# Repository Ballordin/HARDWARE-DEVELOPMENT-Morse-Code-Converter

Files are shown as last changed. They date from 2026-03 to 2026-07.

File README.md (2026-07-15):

#              Temperature to Morse Code Encoder

A professional embedded systems project developed for the Laboratory of Hardware Development (UTeSP - Sistemas Eletrónicos e Computadores). This device monitors ambient temperature using a PT100 sensor and encodes the data into Morse Code, delivered via audio (Buzzer) and visual (LED) signals.

## 🖼️ Hardware Preview

The PCB was designed and modeled in Altium Designer, featuring a compact layout and optimized signal paths for the PT100 conditioning circuit.

## 🛠️ Finished Physical Assembly

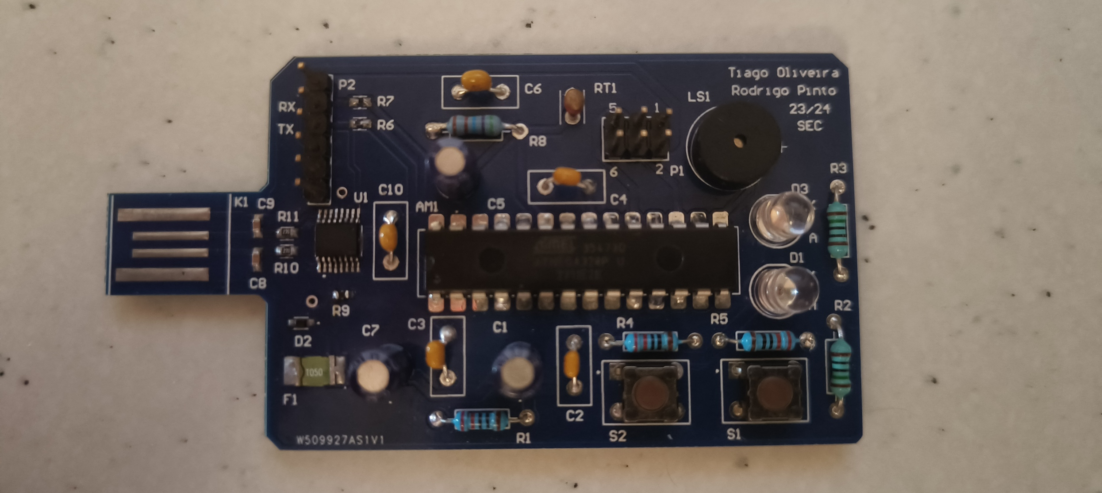
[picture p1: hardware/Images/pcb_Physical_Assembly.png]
Physical Manufactured PCB


## 💻 CAD Design

| 2D PCB Layout | 3D Model Render |
| :---: | :---: |
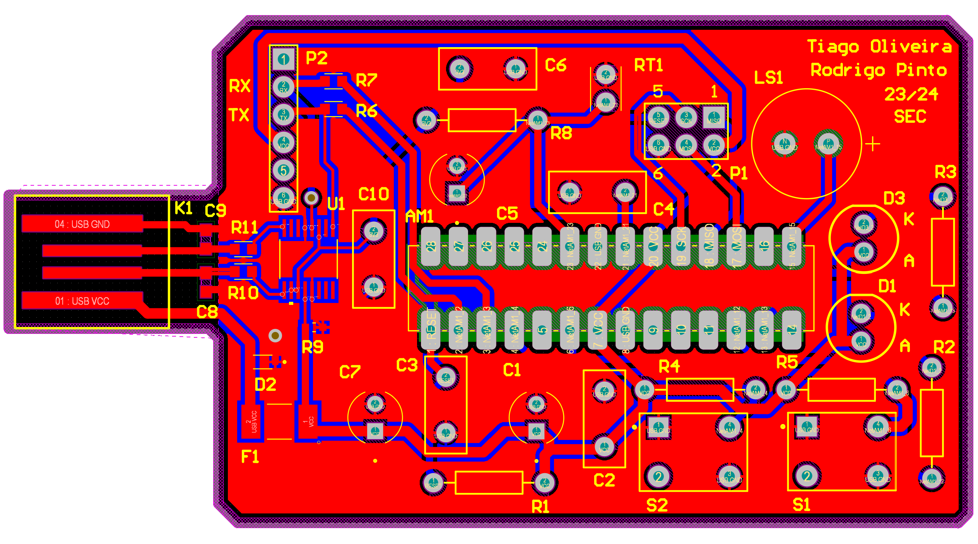
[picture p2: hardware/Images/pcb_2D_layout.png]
2D Layout
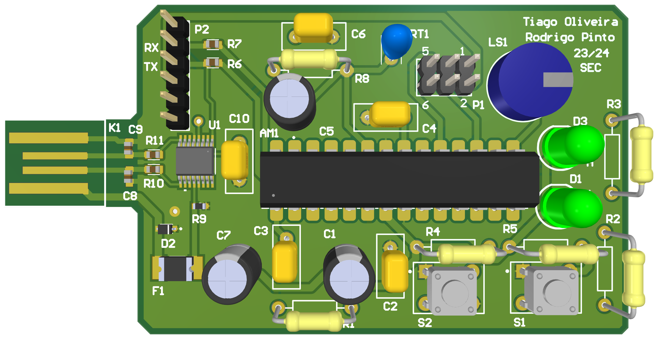
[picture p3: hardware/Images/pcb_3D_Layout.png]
3D Layout
|  |  |

## 🚀 Manufacturing Sponsorship & Quality Review

The physical hardware execution for this project was generously sponsored and fabricated by **PCBWay**. 

### 🌟 Experience & Quality of Service
Working with PCBWay was an absolute breeze from start to finish. A massive shoutout goes to **Liam from the Marketing Department** for reaching out, coordinating this partnership, and providing an immaculate, highly attentive service throughout the entire procurement cycle. 

The fabrication quality delivered by their engineering facility is exceptional:
* **Precision Trace Fabrication:** Flawless copper execution on both layers, accurately preserving the delicate analog signal tracks coming from the PT100 Wheatstone bridge conditioning circuit.
* **Solder Mask & Silk Screen Cleanliness:** The crisp, high-contrast white silk screening over the beautiful blue solder mask makes identifying component designators (like the PTC fuse and decoupling capacitors) effortless during manual assembly.
* **Mechanical Reliability:** Pristine via-plating and perfect drill alignments across all through-hole footprints, ensuring the DIP-28 socket and tactile switches seated perfectly flat against the substrate.

A huge thank you to Liam and the entire [PCBWay](https://www.pcbway.com) team for supporting student engineering projects and providing top-tier manufacturing turnaround!

## 📋 Project Overview

The system features two primary modes of operation, controlled via a TTL serial interface:
Mode 1 (Standard): Real-time temperature monitoring and encoding.
Mode 2 (Manual): Interruption of sensor reading to encode user-provided strings/characters received via UART.

Key Features & Commands
  - Microcontroller: ATmega328P (Running at 8MHz).
  - Baud Rate: 9600 bps (standard) / 115200 bps (high speed).
  - Interactive Commands:
      - '!' : Toggle output between LED and Buzzer.
      - '#' : Toggle between Temperature mode and Manual String mode.
      - '+' / '-' : Increment or decrement the Buzzer tone frequency (PWM).
  - Physical Interface: Two buttons to adjust the Morse transmission speed (BPS).

## 🛠 Hardware Design (Altium Designer)

The hardware focuses on signal integrity and cost-optimization.
  - Signal Conditioning: PT100 RTD integrated into a Wheatstone bridge for precise analog-to-digital conversion.
  - Buzzer: MP-ABI-050-RC (Low-power, 30mA), driven directly by the MCU.
  - Power & Protection: * Integrated USB-to-TTL conversion for power and data.
      - PTC Resettable fuse and decoupling capacitors (10µF and 100nF) for ADC stability and noise filtering.
      - Strategic use of SMD components for high-frequency performance and reliability.

## 💻 Firmware (Embedded C)

The software follows a modular architecture for better maintainability:
  - UART Driver: Custom asynchronous communication handler for serial commands.
  - GPIO & Morse Engine: Optimized dictionary for alphanumeric translation into timed Dot (200ms) and Dash (600ms) sequences.
  - PWM Control: Used for dynamic frequency adjustment of the audio output.
  - Interrupt Handling: Real-time UART RX processing to ensure no characters are lost during transmission.

## 📂 Repository Structure

  - /firmware: C source code, header files, and Atmel Studio project files.
  - /hardware: Altium Designer schematics, PCB layout, and manufacturing Gerbers.
  - /docs: Technical reports, market studies, and project planning.

## 👥 Author
  - Tiago Oliveira (25547)

Institution: IPCA - Escola Técnica Superior Profissional (2023/2024)

---------------------------------------------------------------------------------
## Developed as part of the Laboratory of Hardware Development Course.
---------------------------------------------------------------------------------

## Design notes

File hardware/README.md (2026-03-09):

🛠 Hardware Design

This folder contains all the hardware development files for the Morse Code Temperature Encoder, designed using Altium Designer.

📋 Technical Specifications

The PCB was designed to be a standalone shield/board based on the ATmega328P microcontroller, focused on precision sensing and signal conditioning.

1. Signal Conditioning (PT100 Sensor)
To accurately measure ambient temperature, a PT100 (RTD) sensor was used. Since the resistance variation of a PT100 is very small, the following was implemented:
  - Wheatstone Bridge: Used to convert resistance changes into a measurable voltage differential.
  - ADC Stability: A 100nF decoupling capacitor was placed close to the microcontroller's analog input to filter high-frequency noise and stabilize readings.
2. Power & Protection
  - Integrated USB-to-TTL: The board includes a dedicated section for USB communication, providing both power ($5$V) and data interface.
  - Circuit Protection: A PTC Resettable Fuse (MiniSMDC050F) was added to protect the USB port and the microcontroller from overcurrent.
  - Filtering: A combination of $10$µF electrolytic and $100$nF ceramic capacitors ensures a clean power rail for the MCU.
3. Components & I/O
  - Buzzer: MP-ABI-050-RC electro-mechanical buzzer.
      - Design Note: Selected specifically for its low current draw ($30$mA), allowing it to be driven directly by the ATmega328P I/O pin (max $40$mA) without needing an external transistor.
  - Visual Output: High-brightness Red LED for Morse signaling and a Yellow LED for system status/debugging.
  - User Interface: Two tactile switches for real-time BPS (Bits Per Second) adjustment.

📂 Folder Content

  - /Altium_Project: Native .PrjPcb, .SchDoc, and .PcbDoc files.
  - /Schematics: PDF version of the full circuit schematic.
  - /Gerber: Manufacturing files (RS-274X) for PCB production.
  - /BOM: Bill of Materials with specific Farnell/Mouser part numbers.
  
🖼 Preview

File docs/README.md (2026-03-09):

📄 Project Documentation

This folder contains the formal technical documentation, academic reports, and design analysis for the Morse Code Temperature Encoder project.

📂 Document Overview
1. Final Technical Report

The comprehensive final document covering the entire project lifecycle.

Contents: System architecture, hardware/software integration details, flowcharts, and final testing results.

Key Sections: Technical specifications of the ATmega328P, Morse algorithm implementation, and Wheatstone bridge calculations.

2. Analysis & Design Study
A detailed study of the components and theoretical foundations.

Contents: Market research for component selection (PT100, Buzzer, LEDs), cost analysis, and comparison between SMD vs. THT components for the USB interface.

3. Project Scope & Problem Statement
The initial planning phase of the project.

Contents: Definition of functional requirements (Mode 1: Temperature; Mode 2: Manual Serial Input), non-functional requirements (Baud rate, safety protocols), and project milestones.

4. Hardware Diagrams
Early-stage design concepts and block diagrams.

Contents: High-level system overview showing the interaction between the power protection circuit, the MCU, and the I/O peripherals.

🎓 Academic Context
Course: Laboratory of Hardware Development

Institution: IPCA - Escola Técnica Superior Profissional (Portugal)

Objective: To design a complete embedded system from scratch, including PCB manufacturing and firmware development in C.

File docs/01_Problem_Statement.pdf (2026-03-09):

Problem Statement

Neste documento serão discutidas as etapas para a realização de um projeto de medição de temperatura e conversão em código Morse através de saídas sonoras ou luminosas.

1º Passo – Medição de Temperatura

Para medir a temperatura, poderão ser utilizados sensores de temperatura, RTD, termopares ou termístores. Neste caso será usada uma PT100 numa ponte de wheatstone para fazer a medição de temperatura.

2º Passo – Conversão da Temperatura em Código MORSE

O 1º modo que será o modo standard onde a temperatura lida pelo sensor será codificada em código MORSE e enviada para a saída escolhida, luminosa ou sonora. Código MORSE é lido por “bips”, aos quais podem ser longos ou curtos, e a combinação destes “bips” longos ou curtos, dá origem a uma letra ou número. Sendo assim, neste 1º modo apenas a temperatura será lida em forma de código MORSE.

3º Passo – Conversão de Palavras/carateres emitidos pela porta-série em Código MORSE

O 2º modo consiste no envio de palavras pelo comando porta-série que também serão codificadas em código MORSE em saída luminosa ou sonora. A troca entre o 1º modo e o 2º modo será feita com um símbolo específico como “#” ou “*” enviada pela porta- série.

4º Passo – Saída Luminosa e Sonora

No nosso sistema existirão 2 saídas, saída luminosa ou saída sonora, onde para saída sonora usaremos um Buzzer e para saída luminosa usaremos um LED.

5º Passo – Reprodução do código MORSE por saída luminosa ou sonora

Para a escolha de saída, utilizamos o comando porta-série, onde escolhemos uma letra para representar a saída sonora “B” e outra letra para representar a saída luminosa “L”.

6º Passo – Configuração da frequência de som de operação

A duração da frequência do som de operação poderá ser configurada utilizando o baud_rate na programação do microcontrolador.

7º Passo – Botão para incrementar e decrementar bps

Haverá também um botão que incremente ou decremente a duração da frequência de operação.

a25547 – Tiago Oliveira

a25548 – Rodrigo Pinto

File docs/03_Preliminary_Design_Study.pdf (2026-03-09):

# Codificador de temperatura em Código Morse

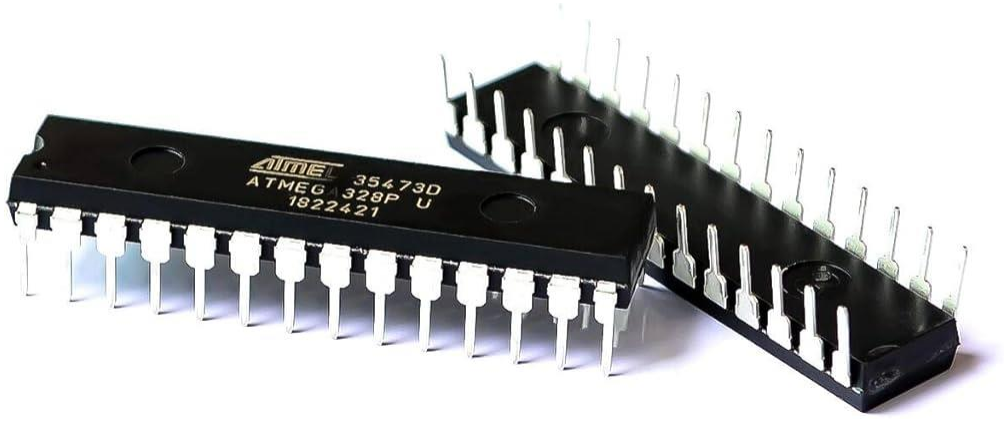
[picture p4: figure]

Tiago Oliveira - 25547
Rodrigo Pinto - 25548

# Problem Statement

O projeto que vamos criar terá dois modos de funcionamento.

## Modo 1: Medir a temperatura e reproduzir os dados em código Morse através de saídas sonoras ou luminosas (escolha feita enviando um comando

pela porta serie TTL).

## Modo 2: Interromper a leitura da temperatura enviando um carater pela porta série. Após essa interrupção será possível fazer a leitura de palavras/caracteres enviadas pela porta série. Leitura também reproduzida

em código Morse através de saídas sonoras ou luminosas.

## Outros requisitos deste projeto são: através de dois botões podemos incrementar ou decrementar os bps do sinal, receber comando para configurar a frequência de som. Usar obrigatoriamente o Baud rate a

115200bps.

# Project Scope

- TÍTULO DO PROJETO: Codificador de Temperatura em Código MORSE
- OBJETIVO DO PROJETO:
- Desenvolver um equipamento que monitora e codifica a temperatura ambiente em código Morse e exibe os resultados em um display LED ou em um Buzzer.
- DESCRIÇÃO DO PROJETO:
- Este projeto tem como objetivo desenvolver um dispositivo eletrônico que mede a temperatura ambiente por meio de um sensor de temperatura PT100 e codifica essa temperatura em código Morse. O dispositivo utilizará o microcontrolador ATmega328P para controlar duas saídas: luminosa (LED) e sonora (buzzer). A comunicação entre o dispositivo e um computador será feita por meio do comando porta série (UART) para configuração e monitorização da temperatura.
- ÂMBITO DO PROJETO:
- O desenvolvimento deste projeto será feito na unidade curricular de Laboratórios e Desenvolvimento de Hardware, proposto pelo prof.: Carlos Silva e Carlos Ferreira

# Block Diagram

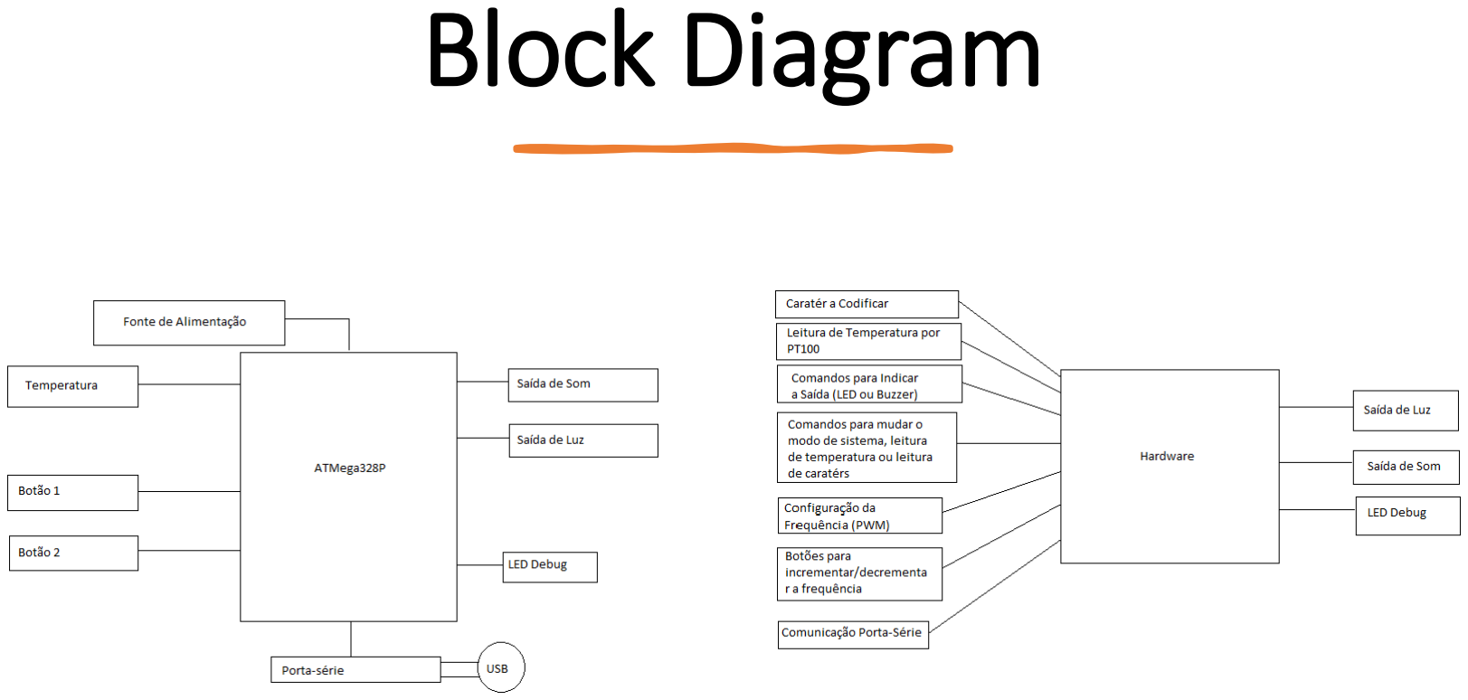
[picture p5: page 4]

# ATMega328P Design

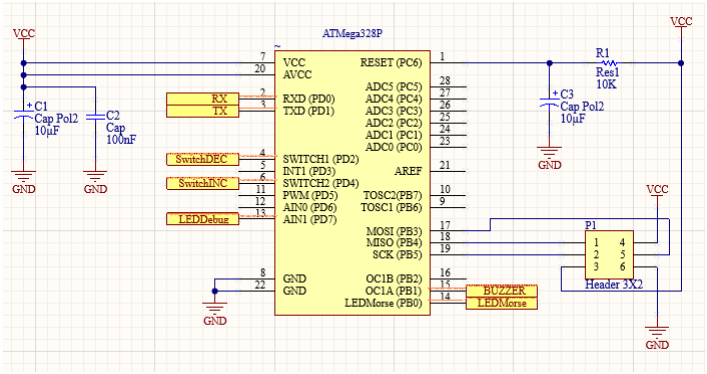
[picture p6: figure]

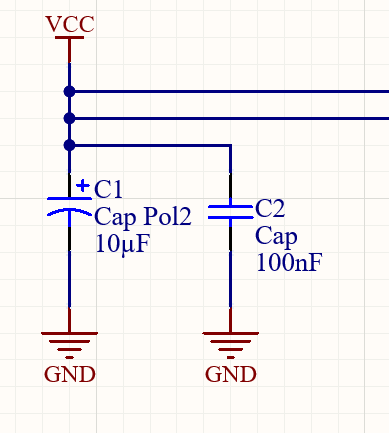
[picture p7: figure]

# ATMega328P Power Circuit

- O ATmega328P precisa de alimentação, sendo assim são utilizado dois condensadores (CAP) ligado ao ground (GND) e à tensão de alimentação (VCC).Este circuito de alimentação tem várias vantagens:
- Filtragem de Ruído: Um condensador pode ser usado para filtrar ruídos e picos de tensão de alta frequência do circuito de alimentação. Um segundo condensador pode ser dimensionado para filtrar ruídos de frequência mais baixa. Isso ajuda a manter uma alimentação mais limpa e estável para os dispositivos que utilizam a energia elétrica.
- Redundância e Confiabilidade
- Tempo de Resposta Rápido

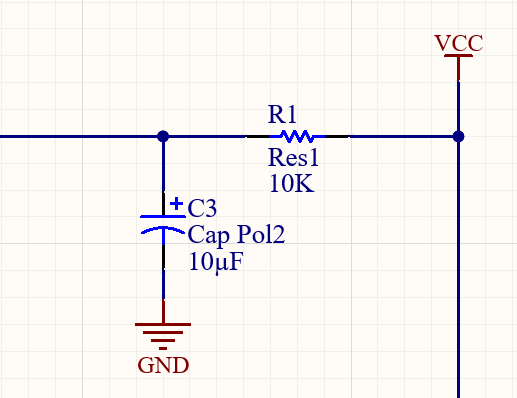
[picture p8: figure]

# ATMega328P Reset Circuit

Uma resistência de pull-up é frequentemente usada em circuitos de reset para garantir que o estado do sinal de reset seja bem definido quando não está sendo ativamente acionado.
Garantia de Estado Lógico: A resistência de pull-up assegura que o sinal de reset permaneça em um estado lógico específico (geralmente "1" ou "alto") quando nenhum outro dispositivo o puxa para um estado lógico "0" ou "baixo". Isso evita estados indefinidos que podem ocorrer quando o sinal de reset fica flutuante.
Temporização de Reset Controlada: O condensador, em conjunto com a resistência (em um circuito RC), pode ser usado para criar um atraso controlado na ativação do reset. O tempo necessário para carregar ou descarregar o condensador determina o atraso na ativação. Isso é útil para garantir que o reset não ocorra imediatamente quando a energia é aplicada, permitindo que o sistema se estabilize primeiro.

# Input Block (Botões)

- Nos diferentes tipos de esquema para montagem de switch, optamos por este tipo de montagem.
- Como a resistência é ligada ao VCC, existirá sempre pull-up interno ou externo mesmo que o pino não esteja bem configurado.
- Mesmo sabendo que o microcontrolador internamente tem uma Resistencia de pull-up mesmo assim decidimos colocar uma Resistencia de pull-up externa

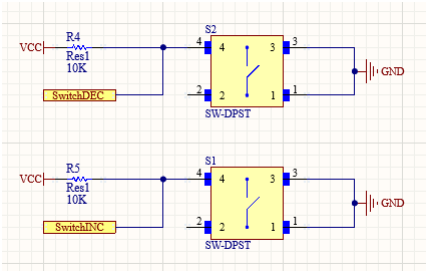
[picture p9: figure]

Possui certas vantagens como:
- Estabilidade: Um resistor de pull-up garante que a entrada permaneça em nível alto (geralmente nível lógico 1) quando o interruptor estiver aberto. Isso evita flutuações indesejadas na entrada.
- Evita curto-circuitos
- Debouncing

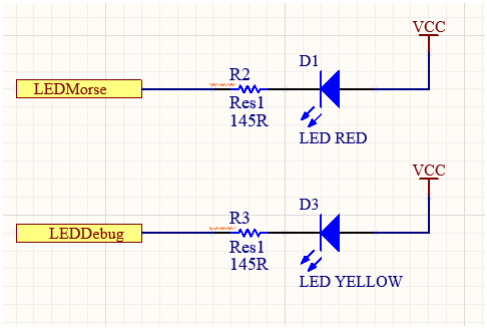
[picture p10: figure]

# Output Block (LED’s)

Calculo de resistências e correntes:

(LED RED)
VFtyp = 2.1V
Ifmax = 20mA
V_LedR = 5 – 2.1 = 2.9V
R_ledR = 2.9/20m = 145 Ω
(Não podemos usar uma resistência inferior a 145 Ω quando alimentada a 5V, pois a probabilidade de danificar o led e as portas do microcontrolador é grande).

(LED YELLOW)
VFtyp = 2.1 V
Ifmax = 20mA
V_ledY = 5 – 2.1 = 2.9V
R_ledY = 2.9/20m = 145 Ω
(Não podemos usar uma resistência inferior a 145 Ω quando alimentada a 5V, pois a probabilidade de danificar o led e as portas do microcontrolador é grande).

# Output Block

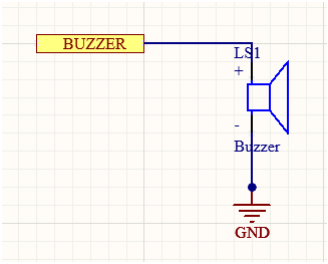
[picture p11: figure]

# (Buzzer)

- Vamos conectar o Buzzer a um PWM.
- Os buzzers tradicionalmente emitem um som com intensidade sonora constante quando alimentados com uma tensão constante. Ao usar um sinal PWM, podemos variar a tensão eficaz aplicada ao buzzer, o que resulta em uma variação na intensidade sonora do som. Isso é útil quando você deseja ajustar o volume do som em um dispositivo ou sistema.

# Output/Input (Conetor Porta-série)

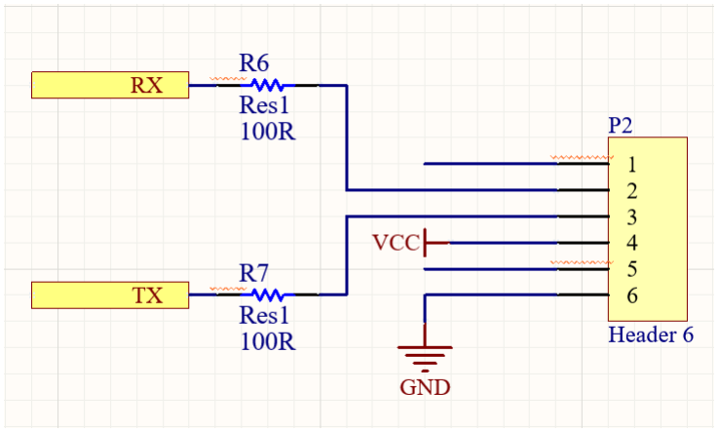
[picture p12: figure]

- Como no nosso projeto será necessária a comunicação porta-série para comunicar entre o utilizador e o microcontrolador, utilizamos o Adaptador série USB para TTL para fazer essas comunicações e assim não necessitamos de adicionar um bloco de conversão UART para fazer essas comunicações.
- As linhas TX e RX do programador são utilizadas para realizar comunicação série assíncrona. Quando o programador recebe um byte do computador via USB, esse byte será transmitido na Linha TX. Quando o programador recebe um byte na linha de entrada RX, esse byte será enviado de volta para o computador através de USB.
- O programador suporta todas as taxas de transmissão inteiras de 300 a 115200bits por segundo, que no nosso caso será feita a 115200 bits, um dos requisitos do nosso projeto.

# Comparação de

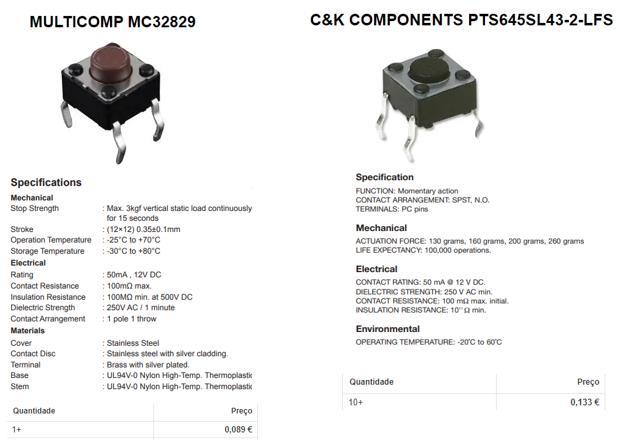
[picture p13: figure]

# Botões

### Neste caso optei pelo tactile switch mais barato, pois ambos os componentes tem características de funcionamento idênticas e cumpre com todos os requisitos necessários para

o nosso projeto.

# Comparação de LED’s (Red)

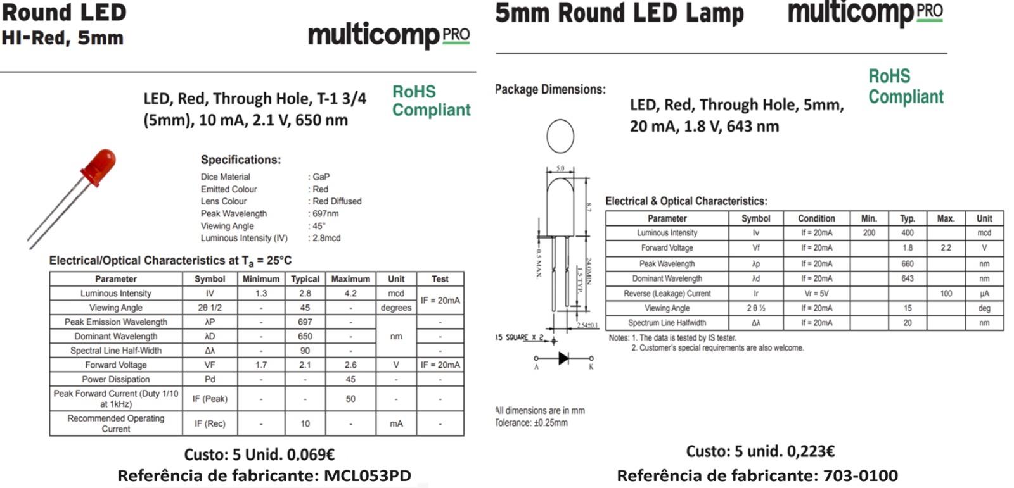
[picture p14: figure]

# Comparação de LED’s (Yellow)

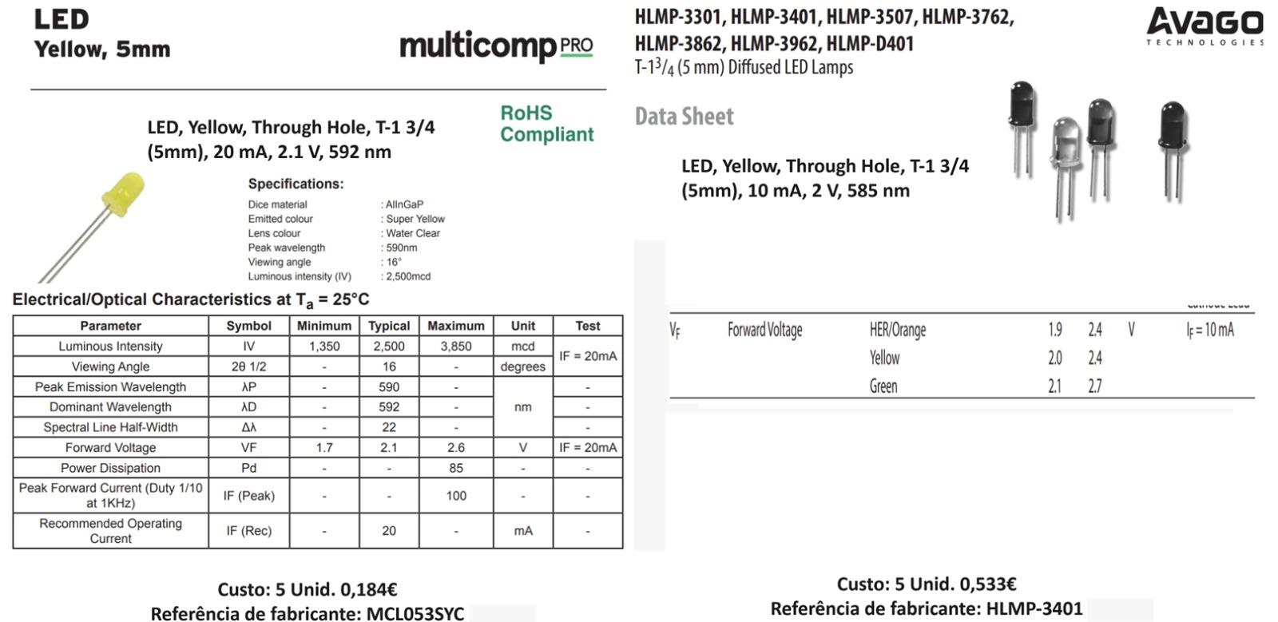
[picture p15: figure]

## - Optei por escolher o MULTICOMP PRO MCL053PD LED, Red, Through Hole, T-1 3/4 (5mm), 10 mA, 2.1 V, 650 nm porque é o componente mais barato entre os dois escolhidos e tendo os dois características idênticas, são ideais para utilizar no nosso

projeto com os requisitos fornecidos.

## - MULTICOMP PRO MCL053SYC LED, Yellow, Through Hole, T-1 3/4 (5mm), 20 mA, 2.1 V, 592 nm porque é o componente mais barato entre os dois escolhidos e tendo os dois características idênticas, são ideais para utilizar no nosso

projeto com os requisitos fornecidos.

# Comparação

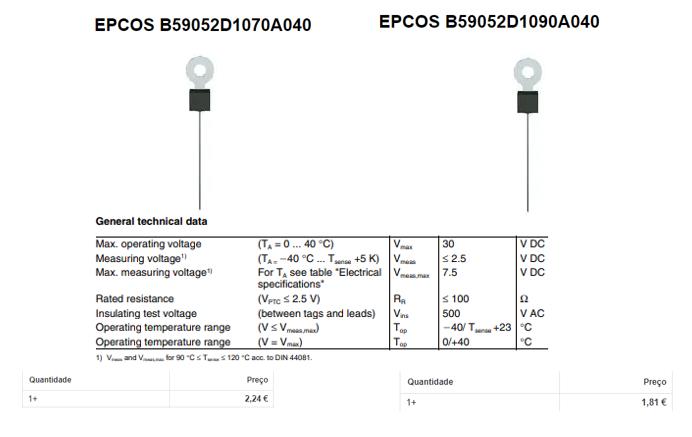
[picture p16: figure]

# Sensores de Temperatura

### - Neste caso optei pelo sensor de temperature mais barato, pois ambos os sensores tem características de funcionamento iguais e cumprem com os requisitos necessários

para o nosso projeto.

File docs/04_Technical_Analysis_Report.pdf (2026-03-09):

# Codificador de temperatura em Código Morse

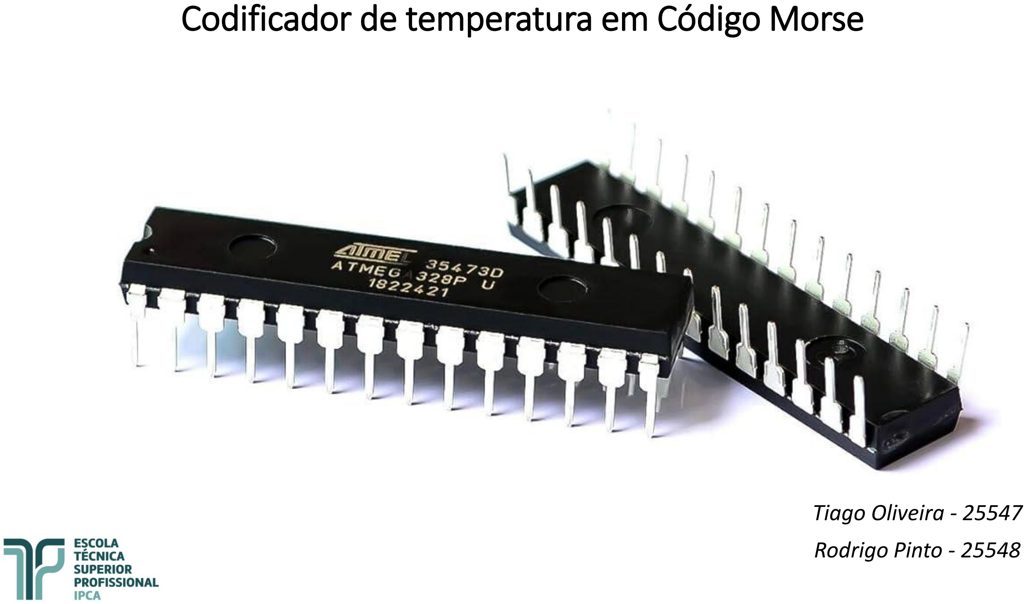
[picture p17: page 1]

### Tiago Oliveira - 25547 Rodrigo Pinto - 25548

# Problem Statement

O projeto que vamos criar terá dois modos de funcionamento.
Modo 1: Medir a temperatura e reproduzir os dados em código Morse através de saídas sonoras ou luminosas (escolha feita enviando um comando pela porta serie TTL).
Modo 2: Interromper a leitura da temperatura enviando um carater pela porta série. Após essa interrupção será possível fazer a leitura de palavras/caracteres enviadas pela porta série. Leitura também reproduzida em código Morse através de saídas sonoras ou luminosas.
Outros requisitos deste projeto são: através de dois botões podemos incrementar ou decrementar os bps do sinal, receber comando para configurar a frequência de som. Usar obrigatoriamente o Baud rate a 115200bps.

# Project Scope

- TÍTULO DO PROJETO: Codificador de Temperatura em Código MORSE
- OBJETIVO DO PROJETO:
- Desenvolver um equipamento que monitora e codifica a temperatura ambiente em código Morse e exibe os resultados em um display LED ou em um Buzzer.
- DESCRIÇÃO DO PROJETO:
- Este projeto tem como objetivo desenvolver um dispositivo eletrônico que mede a temperatura ambiente por meio de um sensor de temperatura PT100 e codifica essa temperatura em código Morse. O dispositivo utilizará o microcontrolador ATmega328P para controlar duas saídas: luminosa (LED) e sonora (buzzer). A comunicação entre o dispositivo e um computador será feita por meio do comando porta série (UART) para configuração e monitorização da temperatura.
- ÂMBITO DO PROJETO:
- O desenvolvimento deste projeto será feito na unidade curricular de Laboratórios e Desenvolvimento de Hardware, proposto pelo prof.: Carlos Silva e Carlos Ferreira

# Block Diagram

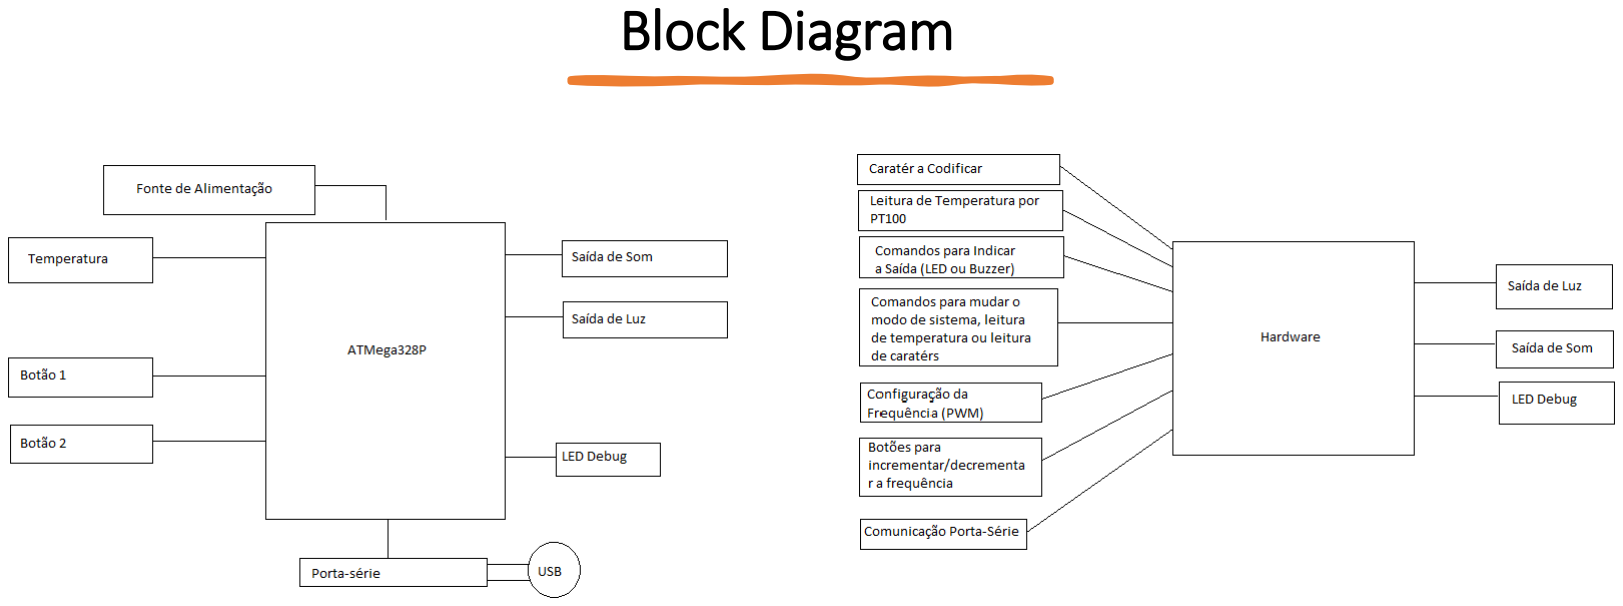
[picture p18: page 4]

# ATMega328P Design

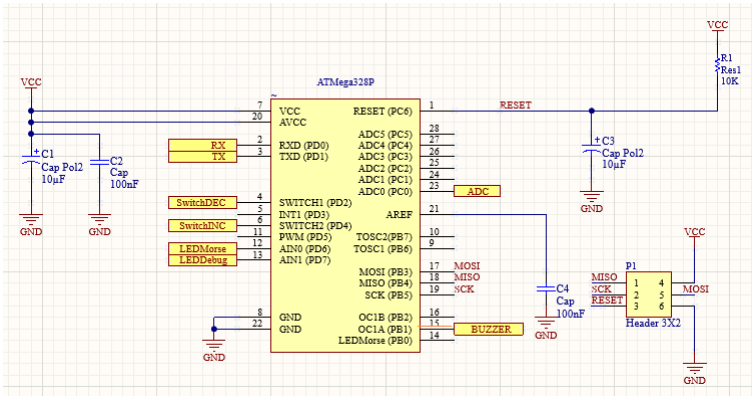
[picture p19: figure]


# ATMega328P Power Circuit

O ATmega328P precisa de alimentação, sendo assim são utilizados dois condensadores (CAP) ligado ao ground (GND) e à tensão de alimentação (VCC) . Este circuito de alimentação tem várias vantagens:

- Filtragem de Ruído: Um condensador pode ser usado para filtrar ruídos e picos de tensão de alta frequência. Um segundo condensador pode ser dimensionado para filtrar ruídos de frequência mais baixa. Isso ajuda a manter uma alimentação mais limpa e estável.
- Redundância e Confiabilidade
- Tempo de Resposta Rápido

# ATMega328P Reset Circuit

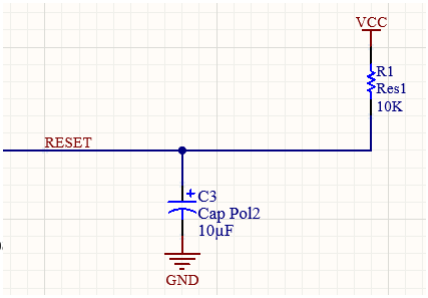
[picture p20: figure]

Uma resistência de pull-up é frequentemente usada em circuitos de reset para garantir que o estado do sinal de reset seja bem definido quando não é ativamente acionado.
Garantia de Estado Lógico: A resistência de pull-up assegura que o sinal de reset permaneça em um estado lógico específico (geralmente"1“)quando nenhum outro dispositivo o puxa para um estado lógico "0". Assim evita estados indefinidos que podem ocorrer quando o sinal de reset fica flutuante. Temporização de Reset Controlada: O condensador, em conjunto com a resistência (em um circuito RC), pode ser usado para criar um atraso controlado na ativação do reset. O tempo necessário para carregar ou descarregar o condensador determina o atraso na ativação. É útil para garantir que o reset não ocorra imediatamente quando a energia é aplicada, fazendo com que o sistema se estabilize primeiro.

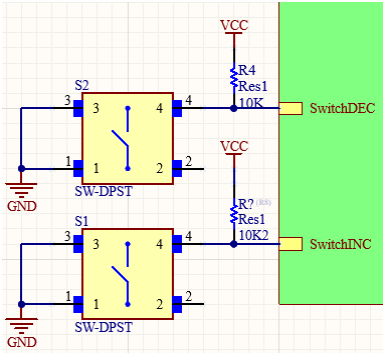
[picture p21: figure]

# Input Block (Botões)

- Nos diferentes tipos de esquema para montagem de switch, optamos por este tipo de montagem.
- Como a resistência é ligada ao VCC, existirá sempre pull-up interno ou externo mesmo que o pino não esteja bem configurado.
- Sabendo que o microcontrolador internamente tem uma Resistencia de pull-up mesmo assim decidimos
colocar uma Resistencia de pull-up externa.
Possui certas vantagens como:
- Estabilidade: Um resistor de pull-up garante que a entrada permaneça em nível alto (nível lógico 1) quando o interruptor estiver aberto. Isso evita flutuações indesejadas na entrada.
- Evita curto-circuitos
- Debouncing

# Input Block (Sensor de Temperatura)

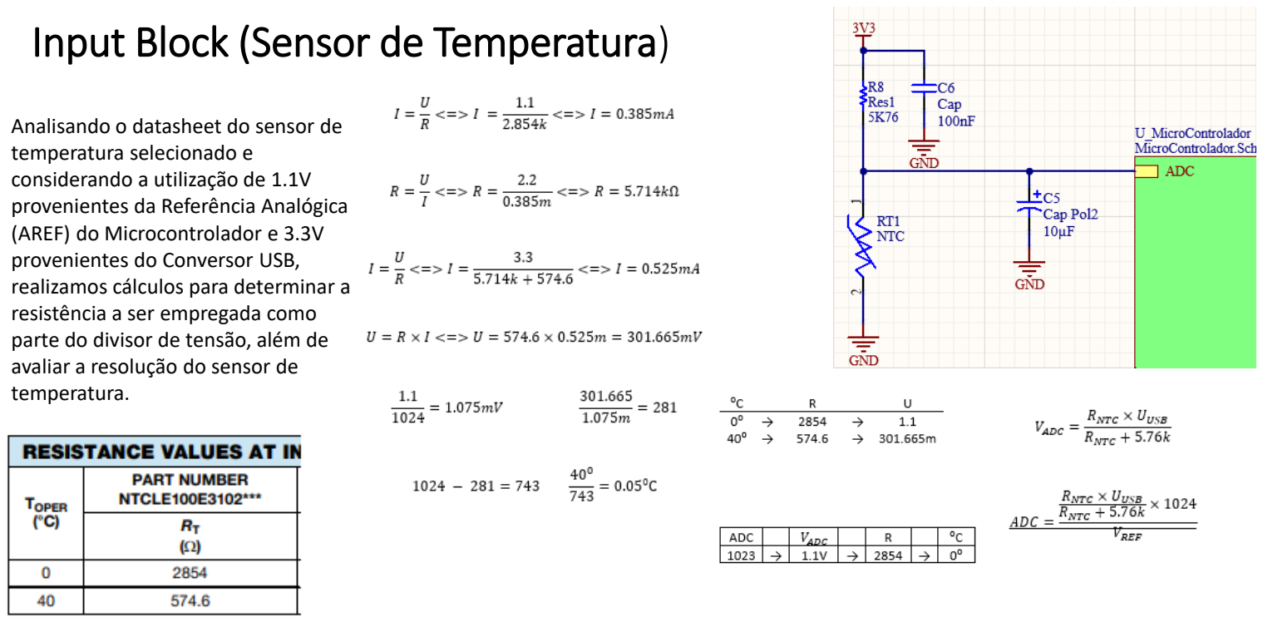
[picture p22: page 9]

Analisando o datasheet do sensor de temperatura selecionado e
considerando a utilização de 1.1V provenientes da Referência Analógica (AREF) do Microcontrolador e 3.3V provenientes do Conversor USB, realizamos cálculos para determinar a resistência a ser empregada como parte do divisor de tensão, além de avaliar a resolução do sensor de temperatura.

# AREF

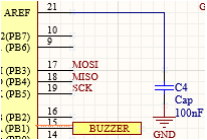
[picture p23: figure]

Usamos o AREF como referência analógica para o ADC.

Conectamos o AREF a um capacitor de 100nF porque ajuda a filtrar ruídos, estabilizar a referência de tensão, compensar correntes de pico e reduzir efeitos de indutância.

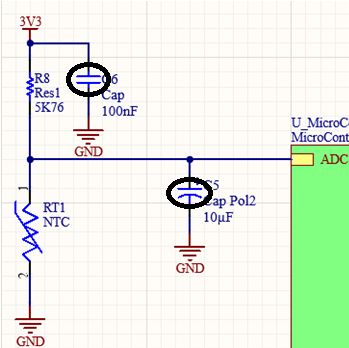
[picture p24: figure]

# Input Block (Sensor de Temperatura)

Estes condensadores de acoplamento possui vantagens para a alimentação do nosso ADC:
- Estabilidade de tensão
O Condensador de 10µF fornece corrente contínua mais estável e suaviza as variações de tensão de alimentação.
- Filtragem de Ruído de Alta Frequência
O Condensador de 100nF é eficaz a filtrar ruídos de alta frequência,ou seja, faz com que o ADC receba uma alimentação o mais limpa possível.
- Resposta Rápida a Variações de Carga
A combinação de condensadores de diferentes valores oferece uma resposta mais eficiente a variações rápidas de carga, garantindo uma alimentação estável.
- Redução de Ripple
O condensador de 10 µF é mais eficaz em lidar com variações de baixa frequência, enquanto o condensador de 100 nF atua em frequências mais altas. Juntos, ajudam a reduzir o ripple na linha de alimentação, proporcionando uma tensão mais constante para o ADC.

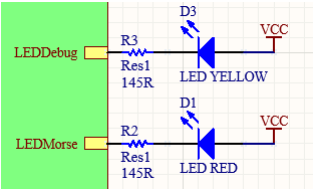
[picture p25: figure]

# Output Block (LED’s)

Calculo de resistências e correntes:

(LED RED)
VFtyp = 2.1V
Ifmax = 20mA
V_LedR = 5 – 2.1 = 2.9V
R_ledR = 2.9/20m = 145 Ω
(Não podemos usar uma resistência inferior a 145 Ω quando alimentada a 5V, pois a probabilidade de danificar o led e as portas do microcontrolador é grande).

(LED YELLOW)
VFtyp = 2.1 V
Ifmax = 20mA
V_ledY = 5 – 2.1 = 2.9V
R_ledY = 2.9/20m = 145 Ω
(Não podemos usar uma resistência inferior a 145 Ω quando alimentada a 5V, pois a probabilidade de danificar o led e as portas do microcontrolador é grande).

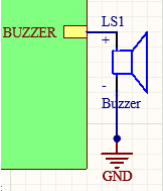
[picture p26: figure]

# Output Block (Buzzer)

Vamos conectar o Buzzer a um PWM.
Ao usar um sinal PWM, podemos variar a tensão eficaz aplicada ao buzzer, o que resulta em uma variação na intensidade sonora do som.
Apenas conectamos um pino à alimentação e o outro pino conectado ao GND. A razão para conectar apenas um terminal do buzzer ao GND é que o circuito interno do buzzer já possui uma conexão entre o terminal positivo e o negativo. Portanto, ao conectar o terminal positivo a uma fonte de alimentação e o terminal negativo (ou GND) ao ponto de referência comum do circuito, o circuito interno do buzzer fica completo.

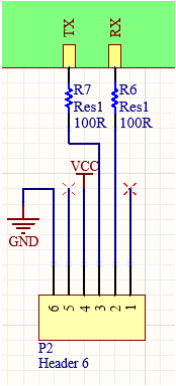
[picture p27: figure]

# Conetor Porta-série

- Como no nosso projeto será necessária a comunicação porta-série para comunicar entre o utilizador e o microcontrolador, utilizamos o Adaptador série USB para TTL para fazer essas comunicações e assim não necessitamos de adicionar um bloco de conversão UART para fazer essas comunicações.
- As linhas TX e RX do programador são utilizadas para realizar comunicação série assíncrona. Quando o programador recebe um byte do computador via USB, esse byte será transmitido na Linha TX. Quando o programador recebe um byte na linha de entrada RX, esse byte será enviado de volta para o computador através de USB.
- O programador suporta todas as taxas de transmissão inteiras de 300 a 115200bits por segundo, que no nosso caso será feita a 115200 bits, um dos requisitos do nosso projeto.

# Conetor Programação

O conector usado para fazer a programação e a comunicação para o microcontrolador é o Pololu USB AVR Programmer v2.1 que usa os pinos MOSI (Master Out Slave In), MISO (Master In Slave Out), SCK (Serial Clock), RESET, VCC (Alimentação) e GND (Terra).


Aqui estão as funções comuns desses pinos:
MOSI (Master Out Slave In): É a linha de dados. No contexto de programação de microcontroladores, este é o canal usado para enviar dados do programador para o microcontrolador.
MISO (Master In Slave Out): É a linha de dados. Utilizado para enviar dados do microcontrolador para o programador.
SCK (Serial Clock): É o sinal de clock . Sincroniza a transferência de dados nos pinos MOSI e MISO.
RESET: Este pino é usado para reiniciar o microcontrolador.
VCC (Alimentação): Este pino fornece a tensão de alimentação ao microcontrolador.
GND (Terra): Fornece um ponto de referência comum para a operação do circuito.

# Circuito de Proteção à Alimentação

Fusível Rearmável:


O fusível é colocado na linha de alimentação para interromper o circuito em caso de correntes anormais, como curtos-circuitos ou sobrecargas.
Díodo TVS:
O díodo é colocado na linha de alimentação para garantir que a corrente flua em uma única direção.
Varistor TVS :
São utilizados para limitar picos de tensão, como os causados por descargas atmosféricas. O varistor conduz corrente quando a tensão ultrapassa um certo limiar, desviando a energia prejudicial e protegendo os dispositivos conectados.
Condensador (filtro de entrada):
O condensador ajuda a filtrar ruídos e picos de tensão que podem ser prejudiciais aos dispositivos conectados.

Como o nosso circuito será alimentado através da porta USB, adotamos componentes essenciais para assegurar a segurança da nossa placa.


# USB Converter

Resistores de 27 ohms : Estas resistências geralmente são utilizadas como resistências de carga. As resistências de carga ajudam a ajustar a impedância do circuito e a garantir que o sinal seja transmitido corretamente.
Condensadores de 47pF : Os condensadores de 47pF são geralmente usados para filtrar ruídos de alta frequência e para ajudar a estabilizar o sinal.
Condensador de 10nF : Este condensador pode ser utilizado para acoplar o sinal, bloqueando qualquer componente DC que possa estar presente, ajuda a garantir que apenas a componente de AC do sinal seja transmitida através do circuito.
Condensador de 100nF : Similar ao capacitor de 10nF, o capacitor de 100nF também pode ser utilizado para acoplamento AC e para ajudar a estabilizar a alimentação do circuito.

# IMPORTÂNCIA DO USO DE SMD

Aqui estão algumas razões pelas quais os componentes SMD são frequentemente preferidos em circuitos de USB Converter:

Desempenho de Alta Frequência:
Componentes SMD têm características elétricas e mecânicas que os tornam ideais para operar em frequências mais altas. Isso é relevante em circuitos de USB Converter, que podem envolver sinais de alta frequência para garantir a transferência eficiente de dados.
Melhor Desempenho Elétrico:
Os componentes SMD geralmente têm características elétricas superiores, como menor indutância e resistência, quando comparados aos componentes tradicionais. Isso é benéfico para garantir um desempenho elétrico mais estável e eficiente.
Aprimoramento da Confiabilidade:
A montagem superficial oferece uma conexão mais direta entre os componentes e a placa de circuito, reduzindo a probabilidade de problemas de soldagem, especialmente em condições de vibração ou variações de temperatura.

# Comparação de Botões

Neste caso optei pelo tactile switch mais barato, pois ambos os componentes tem características de funcionamento idênticas e cumpre com todos os requisitos necessários para o nosso projeto.


https://pt.farnell.com/multicomp/mc32829/tactile-switch-spst-no-0-05a-12v/dp/2543090 (https://pt.farnell.com/multicomp/mc32829/tactile-switch-spst-no-0-05a-12v/dp/2543090) https://pt.farnell.com/c-kcomponents/pts645sl43-2-lfs/tactile-switch-spst-0-05a-12vdc/dp/2435161 (https://pt.farnell.com/c-k-components/pts645sl43-2-lfs/tactile-switch-spst-0-05a-12vdc/dp/2435161)

# Sensor de Temperatura (NTC)

PTC (Positive Temperature Coefficient):
A resistência elétrica de um PTC aumenta com o aumento da temperatura. Ou seja, à medida que a temperatura sobe, a resistência elétrica da PTC também aumenta e a corrente elétrica diminui.
Tendem a ser mais estáveis termicamente em comparação com NTCs.

NTC (Negative Temperature Coefficient):
Ao contrário do PTC, a resistência elétrica de um NTC diminui com o aumento da temperatura. À medida que a temperatura aumenta, a resistência elétrica do NTC diminui e a corrente elétrica aumenta.
Pode ser menos estável termicamente, especialmente em altas temperaturas.

Este foi o sensor de temperatura escolhido por nós, além de ter amplitude de leitura de temperatura requisitada para o nosso sistema,
é o sensor de temperatura mais barato encontrado na FARNELL.


https://pt.farnell.com/vishay/ntcle100e3102jb0a/ntc-thermistor-1kradial-leaded/dp/3020808 (https://pt.farnell.com/vishay/ntcle100e3102jb0a/ntc-thermistor-1k-radial-leaded/dp/3020808)

# Comparação de LED’s (Red)


https://pt.farnell.com/multicomp-pro/mcl053pd/led-5mm-36-hi-red/dp/1581136 (https://pt.farnell.com/multicomp-pro/mcl053pd/led-5mm-36-hi-red/dp/1581136)

https://pt.farnell.com/multicomp/703-0100/led-5mm-red-400mcd-643nm/dp/2112111 (https://pt.farnell.com/multicomp/703-0100/led-5mm-red-400mcd-643nm/dp/2112111)

# Comparação de LED’s (Yellow)


https://pt.farnell.com/multicomp/mcl053syc/led-5mm-16-yellow/dp/1581180 (https://pt.farnell.com/multicomp/mcl053syc/led-5mm-16-yellow/dp/1581180)

https://pt.farnell.com/broadcomlimited/hlmp-3401/led-5mmyellow-5-7mcd-585nm/dp/1003213 (https://pt.farnell.com/broadcom-limited/hlmp-3401/led-5mm-yellow-5-7mcd-585nm/dp/1003213)

- Optei por escolher o MULTICOMP PRO MCL053PD
LED, Red, Through Hole, T-1 3/4 (5mm), 10 mA, 2.1 V, 650 nm
porque é o componente mais barato entre os dois escolhidos e tendo os dois características idênticas, são ideais para utilizar no nosso projeto com os requisitos fornecidos.
- MULTICOMP PRO MCL053SYC
LED, Yellow, Through Hole, T-1 3/4 (5mm), 20 mA, 2.1 V, 592 nm
porque é o componente mais barato entre os dois escolhidos e tendo os dois características idênticas, são ideais para utilizar no nosso projeto com os requisitos fornecidos.

# COMPARAÇÃO DE BUZZER’S


Apesar de ambos os buzzers terem as especificações necessárias ao nosso projeto e terem ambos o mesmo preço de compra, escolhemos o buzzer MP-ABI-050-RC porque sendo a corrente máxima do buzzer 30mA e a corrente máxima da porta do microcontrolador ser 40mA, o buzzer pode ser diretamente conectado à porta.
No caso do outro buzzer, em que a corrente máxima é 50mA, seria necessário o uso de um transitor para controlar a corrente que passaria do buzzer para o pino do microcontrolador.

https://pt.farnell.com/prosignal/abi-050-rc/buzzer-electromechanical-5vdc/dp/2534976 (https://pt.farnell.com/pro-signal/abi-050-rc/buzzer-electro-mechanical-5vdc/dp/2534976)

https://pt.farnell.com/prosignal/abt-414-rc/transducerelectro-mech-audio/dp/2098836 (https://pt.farnell.com/pro-signal/abt-414-rc/transducer-electro-mech-audio/dp/2098836)

# Circuito de Proteção à Alimentação (COMPONENTES)


https://pt.farnell.com/littelfuse/minismdc050f-2/ptc-resettable-fuse-24vdc-1812/dp/1175839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 (https://pt.farnell.com/littelfuse/minismdc050f-2/ptc-resettable-fuse-24vdc-1812/dp/1175839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) https://pt.mouser.com/ProductDetail/Littelfuse/AQ1205-01FTG?qs=tlsG%2FOw5FFgT8
17I6cPGrg%3D%3D (https://pt.mouser.com/ProductDetail/Littelfuse/AQ1205-01FTG?qs=tlsG%2FOw5FFgT817I6cPGrg%3D%3D)

https://pt.farnell.com/yageo/241kd07-tr/varistor-mov-395vdisc-7mm/dp/3052479 (https://pt.farnell.com/yageo/241kd07-tr/varistor-mov-395v-disc-7mm/dp/3052479)

# USB Converter


Este é o componente que será usado para fazer a conversão de sinais de comunicação USB para sinais de comunicação UART.

https://pt.farnell.com/ftdi/ft230xs-xr/i-f-usb2-0-fs-to-basicuart-16ssop/dp/2081321?st=ftdi%20ft230xs-r (https://pt.farnell.com/ftdi/ft230xs-xr/i-f-usb2-0-fs-to-basic-uart-16ssop/dp/2081321?st=ftdi%20ft230xs-r)

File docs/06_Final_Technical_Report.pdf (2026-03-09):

# Codificador de temperatura em Código Morse


### Tiago Oliveira - 25547 Rodrigo Pinto - 25548

# Problem Statement

O projeto que vamos criar terá dois modos de funcionamento.
Modo 1: Medir a temperatura e reproduzir os dados em código Morse através de saídas sonoras ou luminosas (escolha feita enviando um comando pela porta serie TTL).
Modo 2: Interromper a leitura da temperatura enviando um carater pela porta série. Após essa interrupção será possível fazer a leitura de palavras/caracteres enviadas pela porta série. Leitura também reproduzida em código Morse através de saídas sonoras ou luminosas.
Outros requisitos deste projeto são: através de dois botões podemos incrementar ou decrementar os bps do sinal, receber comando para configurar a frequência de som. Usar obrigatoriamente o Baud rate a 115200bps.

# Project Scope

- TÍTULO DO PROJETO: Codificador de Temperatura em Código MORSE
- OBJETIVO DO PROJETO:
- Desenvolver um equipamento que monitora e codifica a temperatura ambiente em código Morse e exibe os resultados em um display LED ou em um Buzzer.
- DESCRIÇÃO DO PROJETO:
- Este projeto tem como objetivo desenvolver um dispositivo eletrônico que mede a temperatura ambiente por meio de um sensor de temperatura PT100 e codifica essa temperatura em código Morse. O dispositivo utilizará o microcontrolador ATmega328P para controlar duas saídas: luminosa (LED) e sonora (buzzer). A comunicação entre o dispositivo e um computador será feita por meio do comando porta série (UART) para configuração e monitorização da temperatura.
- ÂMBITO DO PROJETO:
- O desenvolvimento deste projeto será feito na unidade curricular de Laboratórios e Desenvolvimento de Hardware, proposto pelo prof.: Carlos Silva e Carlos Ferreira

# Comparação de Botões

Neste caso optei pelo tactile switch mais barato, pois ambos os componentes tem características de funcionamento idênticas e cumpre com todos os requisitos necessários para o nosso projeto.


https://pt.farnell.com/multicomp/mc32829/tactile-switch-spst-no-0-05a-12v/dp/2543090 (https://pt.farnell.com/multicomp/mc32829/tactile-switch-spst-no-0-05a-12v/dp/2543090) https://pt.farnell.com/c-kcomponents/pts645sl43-2-lfs/tactile-switch-spst-0-05a-12vdc/dp/2435161 (https://pt.farnell.com/c-k-components/pts645sl43-2-lfs/tactile-switch-spst-0-05a-12vdc/dp/2435161)

# Sensor de Temperatura (NTC)

PTC (Positive Temperature Coefficient):
A resistência elétrica de um PTC aumenta com o aumento da temperatura. Ou seja, à medida que a temperatura sobe, a resistência elétrica da PTC também aumenta e a corrente elétrica diminui.
Tendem a ser mais estáveis termicamente em comparação com NTCs.

NTC (Negative Temperature Coefficient):
Ao contrário do PTC, a resistência elétrica de um NTC diminui com o aumento da temperatura. À medida que a temperatura aumenta, a resistência elétrica do NTC diminui e a corrente elétrica aumenta.
Pode ser menos estável termicamente, especialmente em altas temperaturas.

Este foi o sensor de temperatura escolhido por nós, além de ter amplitude de leitura de temperatura requisitada para o nosso sistema,
é o sensor de temperatura mais barato encontrado na FARNELL.


https://pt.farnell.com/vishay/ntcle100e3102jb0a/ntc-thermistor-1kradial-leaded/dp/3020808 (https://pt.farnell.com/vishay/ntcle100e3102jb0a/ntc-thermistor-1k-radial-leaded/dp/3020808)

# Comparação de LED’s (Red)


https://pt.farnell.com/multicomp-pro/mcl053pd/led-5mm-36-hi-red/dp/1581136 (https://pt.farnell.com/multicomp-pro/mcl053pd/led-5mm-36-hi-red/dp/1581136)

https://pt.farnell.com/multicomp/703-0100/led-5mm-red-400mcd-643nm/dp/2112111 (https://pt.farnell.com/multicomp/703-0100/led-5mm-red-400mcd-643nm/dp/2112111)

# Comparação de LED’s (Yellow)


https://pt.farnell.com/multicomp/mcl053syc/led-5mm-16-yellow/dp/1581180 (https://pt.farnell.com/multicomp/mcl053syc/led-5mm-16-yellow/dp/1581180)

https://pt.farnell.com/broadcomlimited/hlmp-3401/led-5mmyellow-5-7mcd-585nm/dp/1003213 (https://pt.farnell.com/broadcom-limited/hlmp-3401/led-5mm-yellow-5-7mcd-585nm/dp/1003213)

- Optei por escolher o MULTICOMP PRO MCL053PD
LED, Red, Through Hole, T-1 3/4 (5mm), 10 mA, 2.1 V, 650 nm
porque é o componente mais barato entre os dois escolhidos e tendo os dois características idênticas, são ideais para utilizar no nosso projeto com os requisitos fornecidos.
- MULTICOMP PRO MCL053SYC
LED, Yellow, Through Hole, T-1 3/4 (5mm), 20 mA, 2.1 V, 592 nm
porque é o componente mais barato entre os dois escolhidos e tendo os dois características idênticas, são ideais para utilizar no nosso projeto com os requisitos fornecidos.

# COMPARAÇÃO DE BUZZER’S


Apesar de ambos os buzzers terem as especificações necessárias ao nosso projeto e terem ambos o mesmo preço de compra, escolhemos o buzzer MP-ABI-050-RC porque sendo a corrente máxima do buzzer 30mA e a corrente máxima da porta do microcontrolador ser 40mA, o buzzer pode ser diretamente conectado à porta.
No caso do outro buzzer, em que a corrente máxima é 50mA, seria necessário o uso de um transitor para controlar a corrente que passaria do buzzer para o pino do microcontrolador.

https://pt.farnell.com/prosignal/abi-050-rc/buzzer-electromechanical-5vdc/dp/2534976 (https://pt.farnell.com/pro-signal/abi-050-rc/buzzer-electro-mechanical-5vdc/dp/2534976)

https://pt.farnell.com/prosignal/abt-414-rc/transducerelectro-mech-audio/dp/2098836 (https://pt.farnell.com/pro-signal/abt-414-rc/transducer-electro-mech-audio/dp/2098836)

# Circuito de Proteção à Alimentação (COMPONENTES)


https://pt.farnell.com/littelfuse/minismdc050f-2/ptc-resettable-fuse-24vdc-1812/dp/1175839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 (https://pt.farnell.com/littelfuse/minismdc050f-2/ptc-resettable-fuse-24vdc-1812/dp/1175839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) https://pt.mouser.com/ProductDetail/Littelfuse/AQ1205-01FTG?qs=tlsG%2FOw5FFgT8
17I6cPGrg%3D%3D (https://pt.mouser.com/ProductDetail/Littelfuse/AQ1205-01FTG?qs=tlsG%2FOw5FFgT817I6cPGrg%3D%3D)

https://pt.farnell.com/yageo/241kd07-tr/varistor-mov-395vdisc-7mm/dp/3052479 (https://pt.farnell.com/yageo/241kd07-tr/varistor-mov-395v-disc-7mm/dp/3052479)

# USB Converter


Este é o componente que será usado para fazer a conversão de sinais de comunicação USB para sinais de comunicação UART.

https://pt.farnell.com/ftdi/ft230xs-xr/i-f-usb2-0-fs-to-basicuart-16ssop/dp/2081321?st=ftdi%20ft230xs-r (https://pt.farnell.com/ftdi/ft230xs-xr/i-f-usb2-0-fs-to-basic-uart-16ssop/dp/2081321?st=ftdi%20ft230xs-r)

# Restrições de Manejo

## - Uso do ATmega328P

# ATMega328P Design



# ATMega328P Power Circuit

O ATmega328P precisa de alimentação, sendo assim são utilizados dois condensadores (CAP) ligado ao ground (GND) e à tensão de alimentação (VCC) . Este circuito de alimentação tem várias vantagens:

- Filtragem de Ruído: Um condensador pode ser usado para filtrar ruídos e picos de tensão de alta frequência. Um segundo condensador pode ser dimensionado para filtrar ruídos de frequência mais baixa. Isso ajuda a manter uma alimentação mais limpa e estável.
- Redundância e Confiabilidade
- Tempo de Resposta Rápido

# ATMega328P Reset Circuit


Uma resistência de pull-up é frequentemente usada em circuitos de reset para garantir que o estado do sinal de reset seja bem definido quando não é ativamente acionado.
Garantia de Estado Lógico: A resistência de pull-up assegura que o sinal de reset permaneça em um estado lógico específico (geralmente"1“)quando nenhum outro dispositivo o puxa para um estado lógico "0". Assim evita estados indefinidos que podem ocorrer quando o sinal de reset fica flutuante. Temporização de Reset Controlada: O condensador, em conjunto com a resistência (em um circuito RC), pode ser usado para criar um atraso controlado na ativação do reset. O tempo necessário para carregar ou descarregar o condensador determina o atraso na ativação. É útil para garantir que o reset não ocorra imediatamente quando a energia é aplicada, fazendo com que o sistema se estabilize primeiro.


# Input Block (Botões)

- Nos diferentes tipos de esquema para montagem de switch, optamos por este tipo de montagem.
- Como a resistência é ligada ao VCC, existirá sempre pull-up interno ou externo mesmo que o pino não esteja bem configurado.
- Sabendo que o microcontrolador internamente tem uma Resistencia de pull-up mesmo assim decidimos
colocar uma Resistencia de pull-up externa.
Possui certas vantagens como:
- Estabilidade: Um resistor de pull-up garante que a entrada permaneça em nível alto (nível lógico 1) quando o interruptor estiver aberto. Isso evita flutuações indesejadas na entrada.
- Evita curto-circuitos
- Debouncing

# Input Block (Sensor de Temperatura)


Analisando o datasheet do sensor de temperatura selecionado e
considerando a utilização de 1.1V provenientes da Referência Analógica (AREF) do Microcontrolador e 3.3V provenientes do Conversor USB, realizamos cálculos para determinar a resistência a ser empregada como parte do divisor de tensão, além de avaliar a resolução do sensor de temperatura.

# AREF


Usamos o AREF como referência analógica para o ADC.

Conectamos o AREF a um capacitor de 100nF porque ajuda a filtrar ruídos, estabilizar a referência de tensão, compensar correntes de pico e reduzir efeitos de indutância.


# Input Block (Sensor de Temperatura)

Estes condensadores de acoplamento possui vantagens para a alimentação do nosso ADC:
- Estabilidade de tensão
O Condensador de 10µF fornece corrente contínua mais estável e suaviza as variações de tensão de alimentação.
- Filtragem de Ruído de Alta Frequência
O Condensador de 100nF é eficaz a filtrar ruídos de alta frequência,ou seja, faz com que o ADC receba uma alimentação o mais limpa possível.
- Resposta Rápida a Variações de Carga
A combinação de condensadores de diferentes valores oferece uma resposta mais eficiente a variações rápidas de carga, garantindo uma alimentação estável.
- Redução de Ripple
O condensador de 10 µF é mais eficaz em lidar com variações de baixa frequência, enquanto o condensador de 100 nF atua em frequências mais altas. Juntos, ajudam a reduzir o ripple na linha de alimentação, proporcionando uma tensão mais constante para o ADC.


# Output Block (LED’s)

Calculo de resistências e correntes:

(LED RED)
VFtyp = 2.1V
Ifmax = 20mA
V_LedR = 5 – 2.1 = 2.9V
R_ledR = 2.9/20m = 145 Ω
(Não podemos usar uma resistência inferior a 145 Ω quando alimentada a 5V, pois a probabilidade de danificar o led e as portas do microcontrolador é grande).

(LED YELLOW)
VFtyp = 2.1 V
Ifmax = 20mA
V_ledY = 5 – 2.1 = 2.9V
R_ledY = 2.9/20m = 145 Ω
(Não podemos usar uma resistência inferior a 145 Ω quando alimentada a 5V, pois a probabilidade de danificar o led e as portas do microcontrolador é grande).


# Output Block (Buzzer)

Vamos conectar o Buzzer a um PWM.
Ao usar um sinal PWM, podemos variar a tensão eficaz aplicada ao buzzer, o que resulta em uma variação na intensidade sonora do som.
Apenas conectamos um pino à alimentação e o outro pino conectado ao GND. A razão para conectar apenas um terminal do buzzer ao GND é que o circuito interno do buzzer já possui uma conexão entre o terminal positivo e o negativo. Portanto, ao conectar o terminal positivo a uma fonte de alimentação e o terminal negativo (ou GND) ao ponto de referência comum do circuito, o circuito interno do buzzer fica completo.


# Conetor Porta-série

- Como no nosso projeto será necessária a comunicação porta-série para comunicar entre o utilizador e o microcontrolador, utilizamos o Adaptador série USB para TTL para fazer essas comunicações e assim não necessitamos de adicionar um bloco de conversão UART para fazer essas comunicações.
- As linhas TX e RX do programador são utilizadas para realizar comunicação série assíncrona. Quando o programador recebe um byte do computador via USB, esse byte será transmitido na Linha TX. Quando o programador recebe um byte na linha de entrada RX, esse byte será enviado de volta para o computador através de USB.
- O programador suporta todas as taxas de transmissão inteiras de 300 a 115200bits por segundo, que no nosso caso será feita a 115200 bits, um dos requisitos do nosso projeto.

# Conetor Programação

O conector usado para fazer a programação e a comunicação para o microcontrolador é o Pololu USB AVR Programmer v2.1 que usa os pinos MOSI (Master Out Slave In), MISO (Master In Slave Out), SCK (Serial Clock), RESET, VCC (Alimentação) e GND (Terra).


Aqui estão as funções comuns desses pinos:
MOSI (Master Out Slave In): É a linha de dados. No contexto de programação de microcontroladores, este é o canal usado para enviar dados do programador para o microcontrolador.
MISO (Master In Slave Out): É a linha de dados. Utilizado para enviar dados do microcontrolador para o programador.
SCK (Serial Clock): É o sinal de clock . Sincroniza a transferência de dados nos pinos MOSI e MISO.
RESET: Este pino é usado para reiniciar o microcontrolador.
VCC (Alimentação): Este pino fornece a tensão de alimentação ao microcontrolador.
GND (Terra): Fornece um ponto de referência comum para a operação do circuito.

# Circuito de Proteção à Alimentação

Fusível Rearmável:


O fusível é colocado na linha de alimentação para interromper o circuito em caso de correntes anormais, como curtos-circuitos ou sobrecargas.
Díodo TVS:
O díodo é colocado na linha de alimentação para garantir que a corrente flua em uma única direção.
Varistor TVS :
São utilizados para limitar picos de tensão, como os causados por descargas atmosféricas. O varistor conduz corrente quando a tensão ultrapassa um certo limiar, desviando a energia prejudicial e protegendo os dispositivos conectados.
Condensador (filtro de entrada):
O condensador ajuda a filtrar ruídos e picos de tensão que podem ser prejudiciais aos dispositivos conectados.

Como o nosso circuito será alimentado através da porta USB, adotamos componentes essenciais para assegurar a segurança da nossa placa.


# USB Converter

Resistores de 27 ohms : Estas resistências geralmente são utilizadas como resistências de carga. As resistências de carga ajudam a ajustar a impedância do circuito e a garantir que o sinal seja transmitido corretamente.
Condensadores de 47pF : Os condensadores de 47pF são geralmente usados para filtrar ruídos de alta frequência e para ajudar a estabilizar o sinal.
Condensador de 10nF : Este condensador pode ser utilizado para acoplar o sinal, bloqueando qualquer componente DC que possa estar presente, ajuda a garantir que apenas a componente de AC do sinal seja transmitida através do circuito.
Condensador de 100nF : Similar ao capacitor de 10nF, o capacitor de 100nF também pode ser utilizado para acoplamento AC e para ajudar a estabilizar a alimentação do circuito.

# IMPORTÂNCIA DO USO DE SMD

Aqui estão algumas razões pelas quais os componentes SMD são frequentemente preferidos em circuitos de USB Converter:

Desempenho de Alta Frequência:
Componentes SMD têm características elétricas e mecânicas que os tornam ideais para operar em frequências mais altas. Isso é relevante em circuitos de USB Converter, que podem envolver sinais de alta frequência para garantir a transferência eficiente de dados.
Melhor Desempenho Elétrico:
Os componentes SMD geralmente têm características elétricas superiores, como menor indutância e resistência, quando comparados aos componentes tradicionais. Isso é benéfico para garantir um desempenho elétrico mais estável e eficiente.
Aprimoramento da Confiabilidade:
A montagem superficial oferece uma conexão mais direta entre os componentes e a placa de circuito, reduzindo a probabilidade de problemas de soldagem, especialmente em condições de vibração ou variações de temperatura.

# Block Diagram


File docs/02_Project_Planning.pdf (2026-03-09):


10, 2023

UTeSP – Sistemas Eletrónicos e Computadores

Laboratórios de Desenvolvimento de Hardware

Professor:

Carlos Ferreira

Autor:

Tiago Oliveira 25547

Rodrigo Pinto 25548

## Índice

## Índice de Figuras

## Índice de Tabelas

### 1. PROBLEM STATEMENT

Neste documento serão discutidas as etapas para a realização de um projeto de medição de temperatura e conversão em código Morse através de saídas sonoras ou luminosas.

1º Passo – Medição de Temperatura

Para medir a temperatura, poderão ser utilizados sensores de temperatura, RTD, termopares ou termístores. Neste caso será usada uma PT100 numa ponte de wheatstone para fazer a medição de temperatura.

2º Passo – Conversão da Temperatura em Código MORSE

O 1º modo que será o modo standard onde a temperatura lida pelo sensor será codificada em código MORSE e enviada para a saída escolhida, luminosa ou sonora. Código MORSE é lido por “bips”, aos quais podem ser longos ou curtos, e a combinação destes “bips” longos ou curtos, dá origem a uma letra ou número. Sendo assim, neste 1º modo apenas a temperatura será lida em forma de código MORSE.

3º Passo – Conversão de Palavras/carateres emitidos pela porta-série em Código MORSE

O 2º modo consiste no envio de palavras pelo comando porta-série que também serão codificadas em código MORSE em saída luminosa ou sonora. A troca entre o 1º modo e o 2º modo será feita com um símbolo específico como “#” ou “*” enviada pela porta- série.

4º Passo – Saída Luminosa e Sonora

No nosso sistema existirão 2 saídas, saída luminosa ou saída sonora, onde para saída sonora usaremos um Buzzer e para saída luminosa usaremos um LED.

5º Passo – Reprodução do código MORSE por saída luminosa ou sonora

Para a escolha de saída, utilizamos o comando porta-série, onde escolhemos uma letra para representar a saída sonora “B” e outra letra para representar a saída luminosa “L”.

6º Passo – Configuração da frequência de som de operação

A duração da frequência do som de operação poderá ser configurada utilizando o baud_rate na programação do microcontrolador.

IPCA | UTeSP SEC| SDI

7º Passo – Botão para incrementar e decrementar bps

Haverá também um botão que incremente ou decremente a duração da frequência de operação.

### 2. ÂMBITO DO PROJETO

TÍTULO DO PROJETO: Codificador de Temperatura em Código MORSE

OBJETIVO DO PROJETO:
- Desenvolver um equipamento que monitora e codifica a temperatura ambiente em código Morse e exibe os resultados em um display LED ou em um Buzzer.
DESCRIÇÃO DO PROJETO:
- Este projeto tem como objetivo desenvolver um dispositivo eletrônico que mede a temperatura ambiente por meio de um sensor de temperatura PT100 e codifica essa temperatura em código Morse. O dispositivo utilizará o microcontrolador ATmega328P para controlar duas saídas: luminosa (LED) e sonora (buzzer). A comunicação entre o dispositivo e um computador será feita por meio do comando porta série (UART) para configuração e monitorização da temperatura.
ÂMBITO DO PROJETO:
- O desenvolvimento deste projeto será feito na unidade curricular de Laboratórios e Desenvolvimento de Hardware, proposto pelo prof.: Carlos Silva e Carlos Ferreira

## 3. DIAGRAMA DE BLOCOS


IPCA | UTeSP SEC| SDI

### 3.1. DIAGRAMA DE BLOCOS DO SISTEMA

Figura 1 - Diagrama de Blocos do Sistema

### 3.2. DIAGRAMA DE BLOCOS DO HARDWARE

Figura 2 - Diagrama de Blocos do Hardware

## 4. RECURSOS USADOS

Hardware:

1. Microcontrolador ATmega328P DIP 28pinos.
2. Sensor de temperatura PT100.
3. LED para a saída luminosa e LED Debug
4. Buzzer para a saída sonora.
5. Botões DIP Tactile
5. Conversor UART para comunicação serial.

6 Placa de circuito impresso (PCB).

7. Fonte de alimentação.
8. Componentes eletrônicos diversos (resistências, capacitores, etc.).
9. ICSP 2x3 2,54mm para fazer a programação do ATmega328P
10. PWM para configuração da frequência de som de operação

Software:

1. MicroChip Studio/Visual Code: Desenvolvimento do software do nosso sistema.
2. Documentação do projeto e do software.
3. Paint: Desenho dos Diagrama de Blocos
4. Word: Desenvolvimento dos vários relatórios
5. OnlineGantt.com: Templates para os diagramas de Gantt
6. Altium Design: Desenvolvimento do Hardware, Layout e PCB.

IPCA | UTeSP SEC| SDI

## 5. TAREFAS E RESPONSABILIDADES

Tabela 1 - Tabela das Tarefas e Responsabilidades

Tarefas | 16-23 out 23-30 out 30-6 nov 6-13 nov Responsável
Desenho de Circuito Elétrico | Tiago/Rodrigo
Estudo do Código Morse | Tiago
Estudo do Decodificador | Tiago
Estudo do ATMega328P | Rodrigo
Estudo do Circuito de Alimentação e Reset | Tiago/Rodrigo
Estudo da Configuração da frequência (PWM) | Tiago
Estudo da Comunicação porta-série (UART) | Rodrigo
Definição dos componentes e do circuito elétrico no Altium | Rodrigo

Definição da PCB e
Layout

Tiago

Desenvolvimento do
Software do Circuito
Elétrico

Tiago

Montagem da PCB | Rodrigo
Teste de Software e Hardware | Tiago/Rodrigo

## 6. DIAGRAMA DE GANTT


Figura 3 - Diagrama de Gantt

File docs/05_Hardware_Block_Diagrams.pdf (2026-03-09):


Controlo Lógico da Barreira de um Parque de Estacionamento

{11, 2023}

UTeSP – Sistemas Eletrónicos e Computadores

Laboratórios de Desenvolvimento de Hardware

Professor:

Carlos Ferreira

Autor(s):

Tiago Oliveira 25547

Rodrigo Pinto 25548


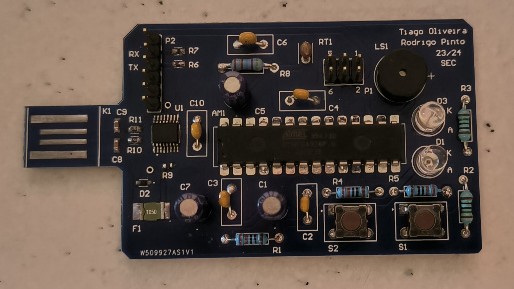
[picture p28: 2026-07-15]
hardware/Images/pcb_Physical_Board.jpg

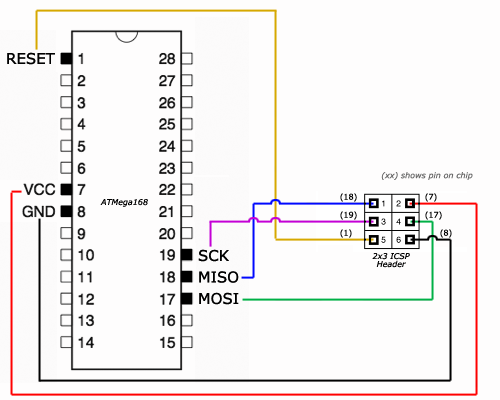
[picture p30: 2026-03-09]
hardware/Images/icsp_hookup.webp

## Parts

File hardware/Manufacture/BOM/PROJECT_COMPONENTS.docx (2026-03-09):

https://pt.farnell.com/harwin/m20-9970345/conn-header-6pos-2row-2-54mm/dp/3756371?st=m20%20997 – ICSP PROGRAMAÇÃO (HEADER 2x3)

https://pt.farnell.com/tdk/fa28x8r1e104knu06/cap-aec-q200-0-1uf-25v-mlcc-radial/dp/3416633 – CAPACITOR 100nF Cerâmica

https://pt.farnell.com/kemet/esk106m063ac3aa/cap-10-f-63v-20/dp/2069035 https://pt.farnell.com/teapo/kss106m016s1a5b07k/cap-10-f-16v-20/dp/2901338 - CAPACITOR 10uF Eletrólitico

https://pt.farnell.com/c-k-components/pts645sl43-2-lfs/tactile-switch-spst-0-05a-12vdc/dp/2435161
https://pt.farnell.com/multicomp/mc32829/tactile-switch-spst-no-0-05a-12v/dp/2543090

- TACTILE SWITCH

https://pt.farnell.com/multicomp/mcf-0-25w-3m9/res-3m9-5-250mw-axial-carbon-film/dp/1186242
- RESISTOR 1/4 WATT

https://pt.farnell.com/amphenol-communications-solutions/10129380-906002blf/conn-header-6pos-1row-2-54mm/dp/3728437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
– HEADER CONNECTOR 1x6

https://pt.farnell.com/pro-signal/abi-050-rc/buzzer-electro-mechanical-5vdc/dp/2534976
- BUZZER

https://pt.farnell.com/multicomp-pro/mcl053pd/led-5mm-36-hi-red/dp/1581136

https://pt.farnell.com/multicomp/703-0100/led-5mm-red-400mcd-643nm/dp/2112111

- LED’s RED

https://pt.farnell.com/multicomp/mcl053syc/led-5mm-16-yellow/dp/1581180

https://pt.farnell.com/broadcom-limited/hlmp-3401/led-5mm-yellow-5-7mcd-585nm/dp/1003213

- LED’s YELLOW

https://pt.farnell.com/vishay/ntcle100e3102jb0a/ntc-thermistor-1k-radial-leaded/dp/3020808 - TEMPERATURE SENSOR

https://pt.farnell.com/ftdi/ft230xs-xr/i-f-usb2-0-fs-to-basic-uart-16ssop/dp/2081321?st=ftdi%20ft230xs-r – USB CONVERTER

https://pt.farnell.com/walsin/wr06x270-jtl/res-27r-5-0-1w-0603-thick-film/dp/2670728 (ESTA)
https://pt.farnell.com/bourns/cr0603-fx-27r0elf/res-27r-1-0-1w-0603-thick-film/dp/2333611
- RESISTÊNCIA 27 Ohms

https://pt.farnell.com/multicomp/mc0603n470j500ct/cap-47pf-50v-5-c0g-np0-0603/dp/1759062 (ESTA)

https://pt.farnell.com/walsin/0603n470j500ct/cap-47pf-50v-5-c0g-np0-0603/dp/2496905
- CONDENSADOR 47pF

https://pt.farnell.com/tdk/c1608x8r1e104m080aa/cap-0-1uf-25v-mlcc-0603/dp/3489836RL
- CONDENSADOR 100nF SMD

https://pt.farnell.com/koa-speer-electronics/mf1-4dct52r5761f/res-5k76-0-25w-axial-metal-film/dp/3541444
- RESISTENCIA DA NTC

https://pt.farnell.com/littelfuse/minismdc050f-2/ptc-resettable-fuse-24vdc-1812/dp/1175839RL?ost=1175839rl
- FUSÍVEL DA USB

https://pt.mouser.com/ProductDetail/Littelfuse/AQ1205-01ETG?qs=TCDPyi3sCW2VfoQH%2FYUj8g%3D%3D
- DÍODO DA USB

https://pt.farnell.com/panasonic/ezjz1v500aa/varistor-0603-5v-2-1pf/dp/1892557
- VARISTOR DA USB

https://pt.farnell.com/multicomp/mcwr04x1200ftl/res-120r-1-0-0625w-thick-film/dp/2447103
- RESISTENCIA 120 Ohms
https://pt.farnell.com/te-connectivity/lr0204f150r/res-150r-1-250mw-axial-metal-film/dp/2329872
- RESISTENCIA 150 Ohms

https://pt.farnell.com/koa-speer-electronics/mf1-4dct52r5761f/res-5k76-0-25w-axial-metal-film/dp/3541444
- RESISTENCIA 5k76 OHMS

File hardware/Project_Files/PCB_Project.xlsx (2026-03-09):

Comment | Designator | Quantity | Value | Manufacturer | Manufacturer_Reference_ID | Supplier | Supplier_Reference_ID | Supplier_Link
ATMega328P | AM1 | 1
CAP POL | C1, C3, C5, C7 | 4 | 10µF | TEAPO | KSS106M016S1A5B07K | FARNELL | 2901338 | https://pt.farnell.com/teapo/kss106m016s1a5b07k/cap-10-f-16v-20/dp/2901338
CAP NON POL | C2, C4, C6, C10 | 4 | 100nF | TDK | FA28X8R1E104KNU06 | FARNELL | 3416633 | https://pt.farnell.com/tdk/fa28x8r1e104knu06/cap-aec-q200-0-1uf-25v-mlcc-radial/dp/3416633
CAP SMD | C8, C9 | 2 | 47pF | MULTICOMP PRO | MC0603N470J500CT | FARNELL | 1759062 | https://pt.farnell.com/multicomp/mc0603n470j500ct/cap-47pf-50v-5-c0g-np0-0603/dp/1759062
LED RED | D1 | 1 |  | MULTICOMP PRO | MCL053PD | FARNELL | 1581136 | https://pt.farnell.com/multicomp-pro/mcl053pd/led-5mm-36-hi-red/dp/1581136
DIODO TVS | D2 | 1 |  | LITTELFUSE | AQ1205-01FTG | MOUSER ELETRONICS | 576-AQ1205-01FTG | https://pt.mouser.com/ProductDetail/Littelfuse/AQ1205-01FTG?qs=tlsG%2FOw5FFgT817I6cPGrg%3D%3D
LED YELLOW | D3 | 1 |  | MULTICOMP PRO | MCL053SYC | FARNELL | 1581180 | https://pt.farnell.com/multicomp/mcl053syc/led-5mm-16-yellow/dp/1581180
FUSIVEL | F1 | 1 |  | LITTELFUSE | MINISMDC050F-2 | FARNELL | 1175839RL | https://pt.farnell.com/littelfuse/minismdc050f-2/ptc-resettable-fuse-24vdc-1812/dp/1175839RL?ost=1175839rl
BUZZER | LS1 | 1 |  | MULTICOMP PRO | MP-ABI-050-RC | FARNELL | 2534976 | https://pt.farnell.com/pro-signal/abi-050-rc/buzzer-electro-mechanical-5vdc/dp/2534976
SERIAL PORT COMM | P1 | 1 |  | HARWIN | M20-9970345 | FARNELL | 3756371 | https://pt.farnell.com/harwin/m20-9970345/conn-header-6pos-2row-2-54mm/dp/3756371?st=m20%20997
POLOLU AVR PROG | P2 | 1 |  | AMPHENOL | 10129380-906002BLF | FARNELL | 3728437 | https://pt.farnell.com/amphenol-communications-solutions/10129380-906002blf/conn-header-6pos-1row-2-54mm/dp/3728437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
RES THT | R1, R4, R5 | 3 | 10K | MULTICOMP PRO | MCF 0.25W 3M9 | FARNELL | 1186242 | https://pt.farnell.com/multicomp/mcf-0-25w-3m9/res-3m9-5-250mw-axial-carbon-film/dp/1186242
RES THT | R2, R3 | 2 | 150R | TE CONNECTIVITY | LR0204F150R | FARNELL | 2329872 | https://pt.farnell.com/te-connectivity/lr0204f150r/res-150r-1-250mw-axial-metal-film/dp/2329872
RES THT | R8 | 1 | 5K76 | KOA | MF1/4DCT52R5761F | FARNELL | 3541444 | https://pt.farnell.com/koa-speer-electronics/mf1-4dct52r5761f/res-5k76-0-25w-axial-metal-film/dp/3541444
RES SMD | R6, R7 | 2 | 120R | MULTICOMP PRO | MCWR04X1200FTL | FARNELL | 2447103 | https://pt.farnell.com/multicomp/mcwr04x1200ftl/res-120r-1-0-0625w-thick-film/dp/2447103
RES SMD | R10, R11 | 2 | 27R | WALSIN | WR06X270 JTL | FARNELL | 2670728 | https://pt.farnell.com/walsin/wr06x270-jtl/res-27r-5-0-1w-0603-thick-film/dp/2670728
VARISTOR | R9 | 1 |  | YAGEO | 241KD07-TR | FARNELL | 3052479 | https://pt.farnell.com/yageo/241kd07-tr/varistor-mov-395v-disc-7mm/dp/3052479
NTC | RT1 | 1 |  | VISHAY | NTCLE100E3102JB0A | FARNELL | 3020808 | https://pt.farnell.com/vishay/ntcle100e3102jb0a/ntc-thermistor-1k-radial-leaded/dp/3020808
SWITCH | S1, S2 | 2 |  | MULTICOMP | MC32829 | FARNELL | 2543090 | https://pt.farnell.com/multicomp/mc32829/tactile-switch-spst-no-0-05a-12v/dp/2543090
USB CONVERTER | U1 | 1 |  | FTDI CHIP | FT230XS-R | FARNELL | 2081321 | https://pt.farnell.com/ft+I2:I22di/ft230xs-xr/i-f-usb2-0-fs-to-basic-uart-16ssop/dp/2081321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

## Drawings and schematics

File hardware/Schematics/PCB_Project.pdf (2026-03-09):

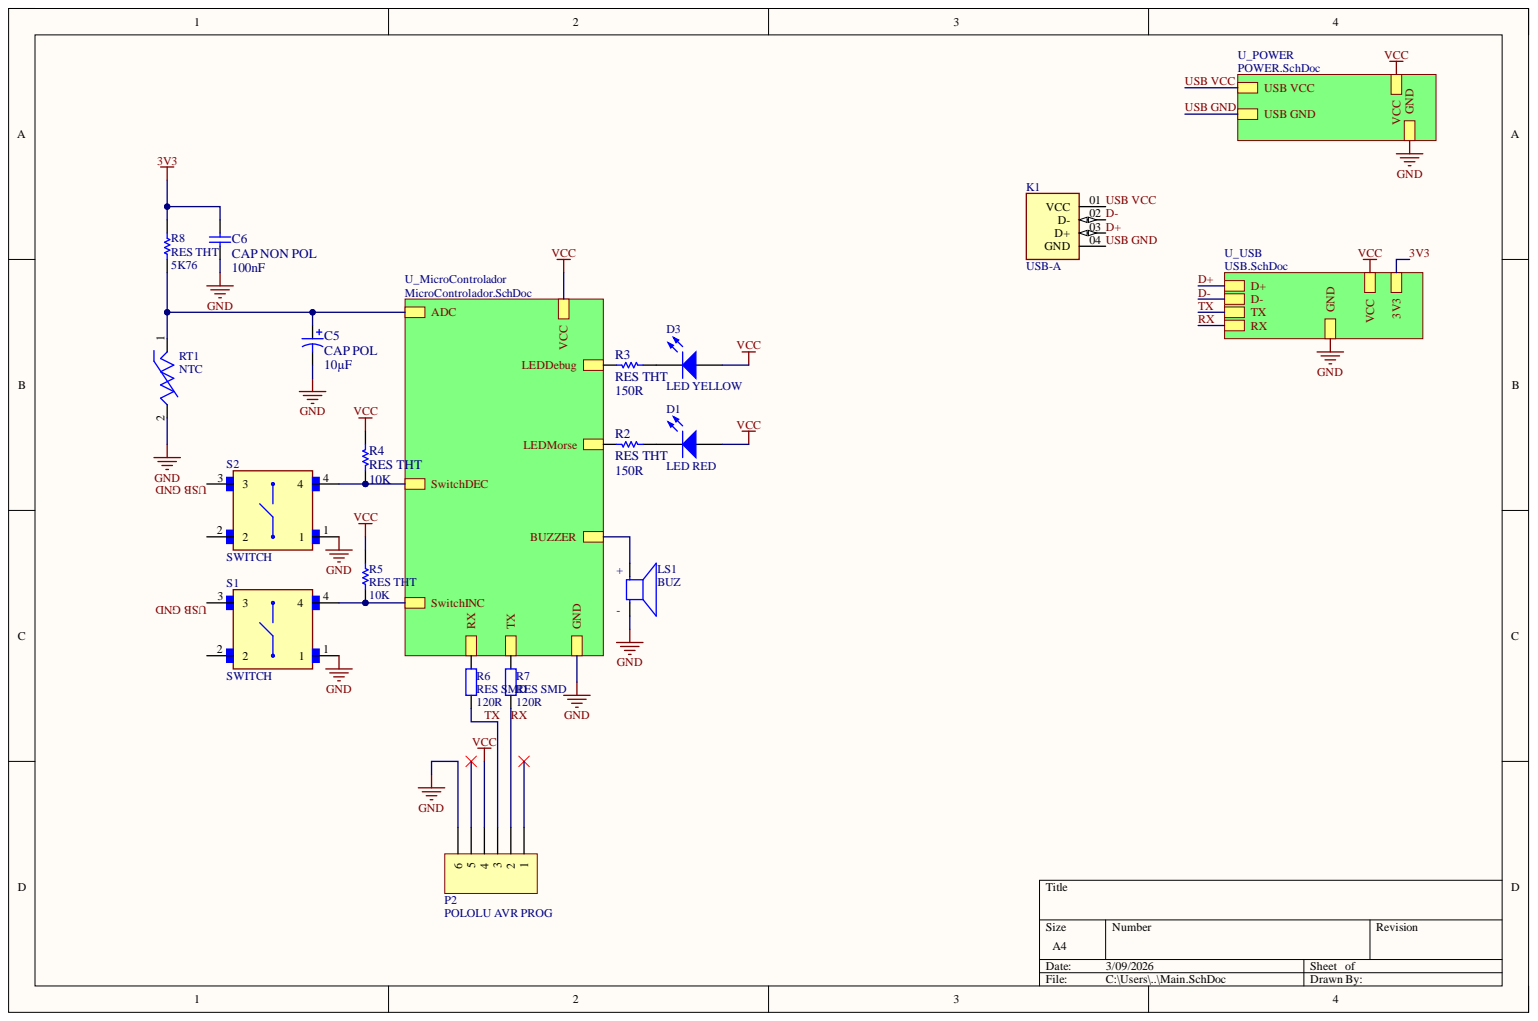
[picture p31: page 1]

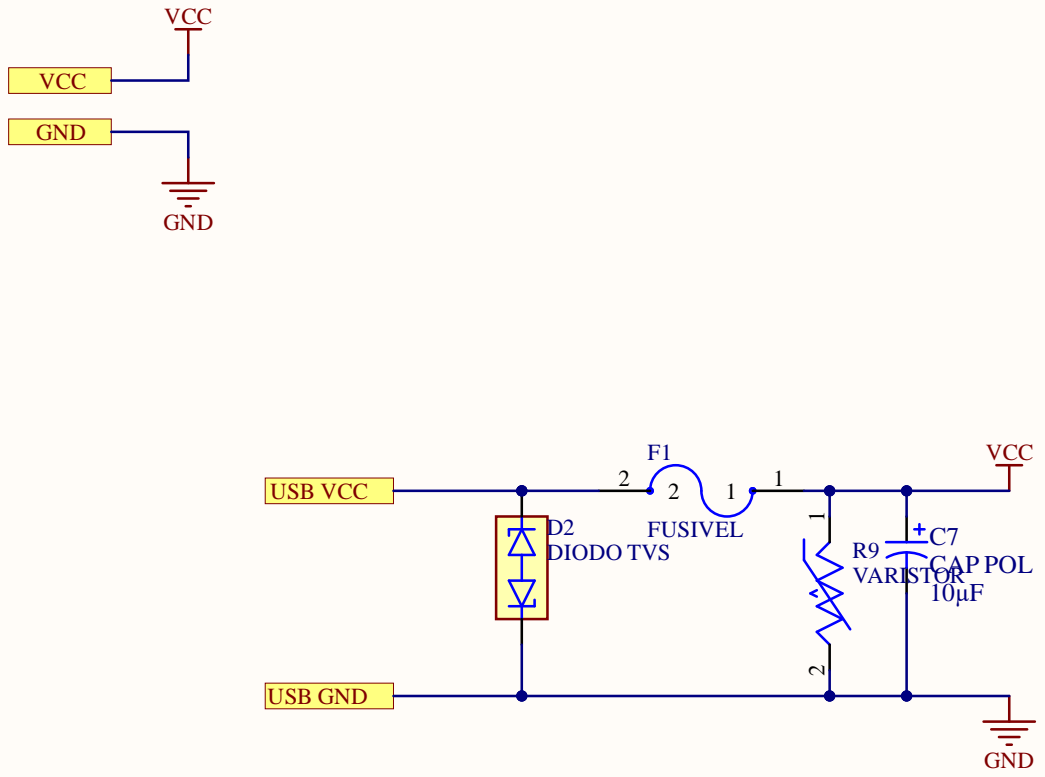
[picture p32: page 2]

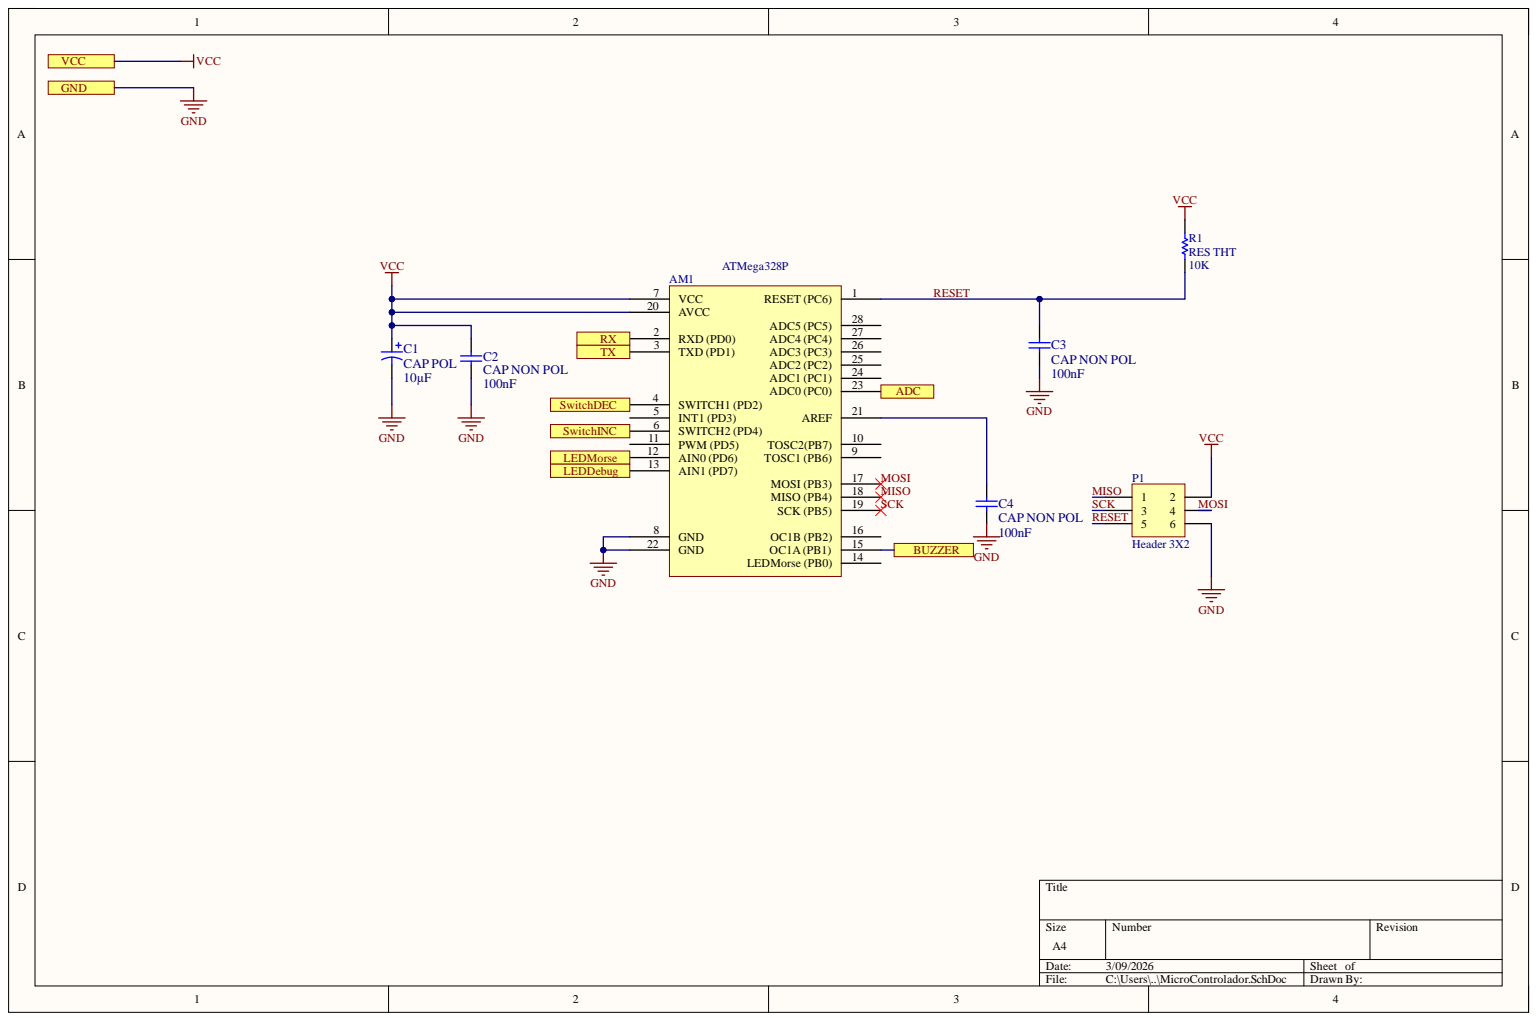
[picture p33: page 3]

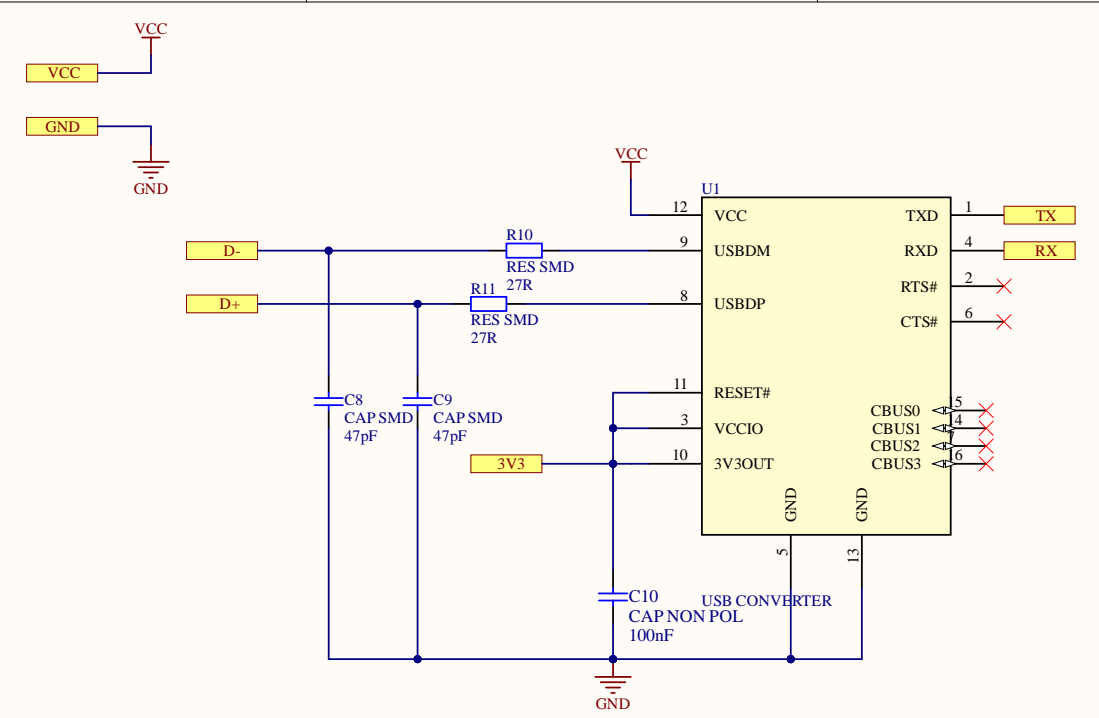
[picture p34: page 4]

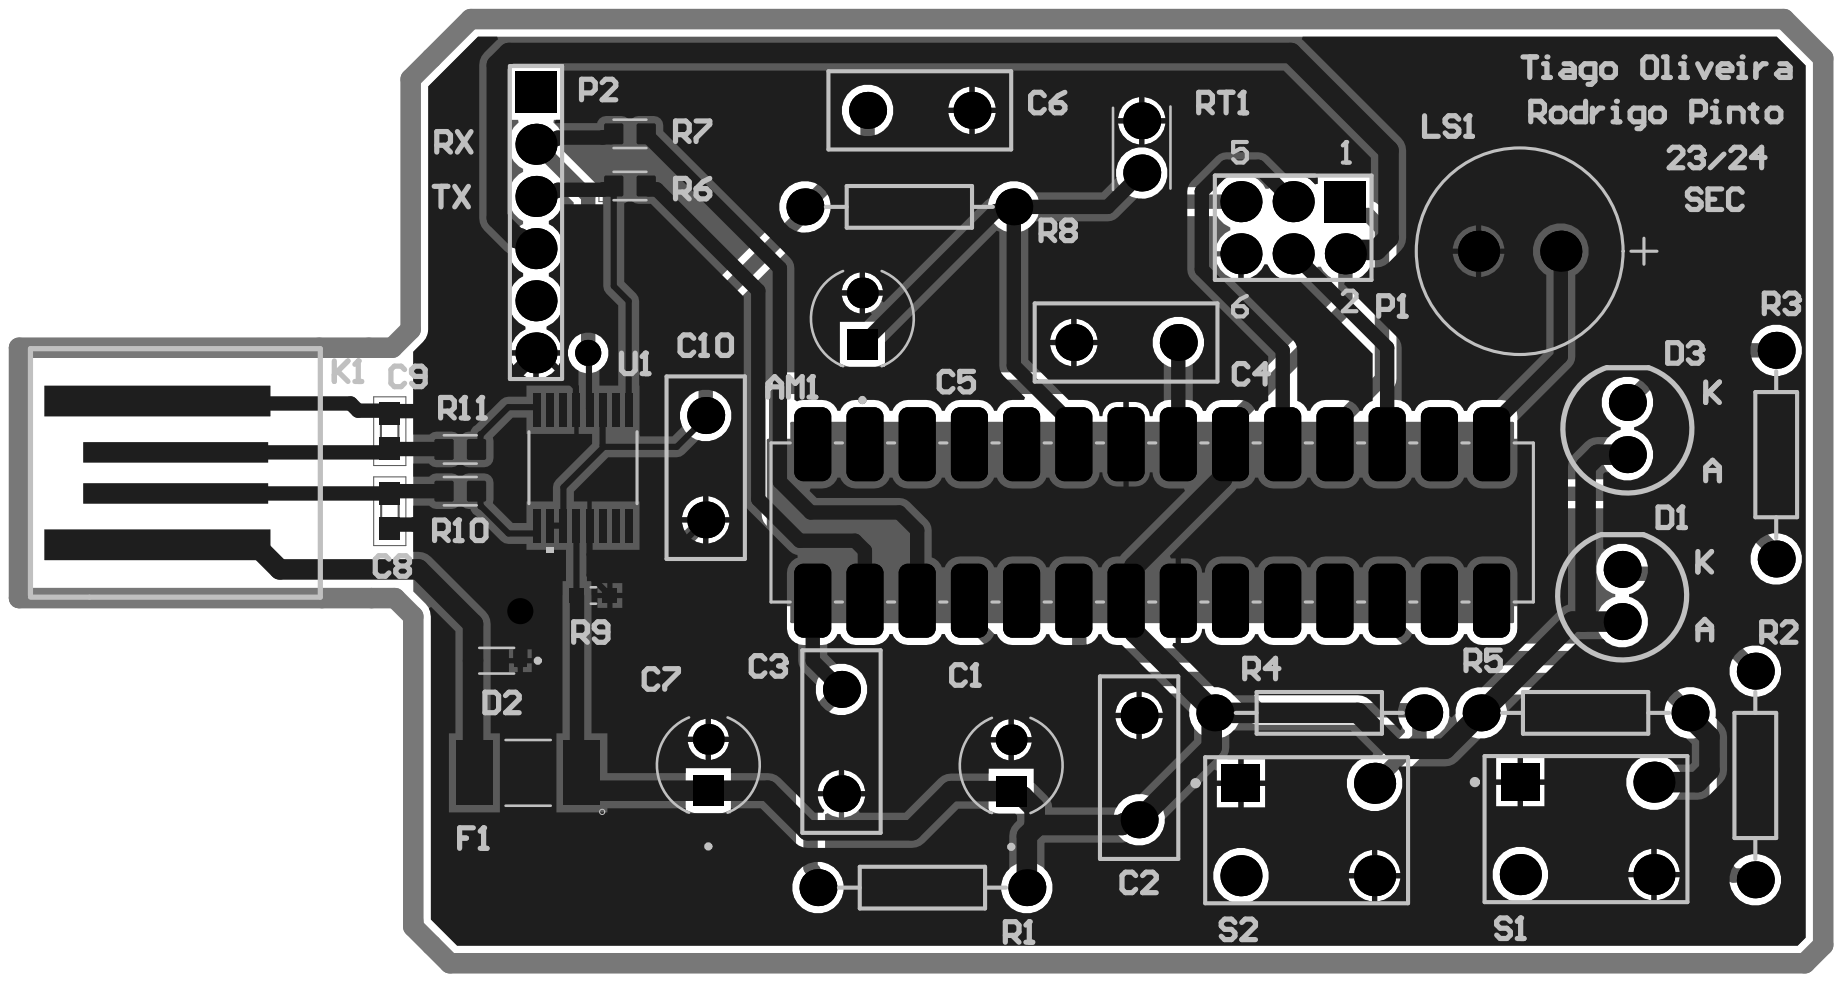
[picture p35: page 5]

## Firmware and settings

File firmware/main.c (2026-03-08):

#include <avr/io.h>
#include <util/delay.h>
#include <avr/interrupt.h>
#include <avr/pgmspace.h>
#include <stdbool.h>
#include <string.h>

/* Custom Modules  */
#include "UART.h"
#include "GPIO.h"

/* End of Custom Modules */


/* Global Vars */
volatile char receivedData[MAX_BUFFER_SIZE];
volatile uint8_t bufferIndex = 0;
volatile uint8_t tone = 100;
bool MORSE = true;

bool cleanstring;
volatile uint8_t sendstring = 0;
/* End Global Vars */
ISR(USART_RX_vect){
	char data = UDR0;

	// Check if buffer is not full
	if (bufferIndex < MAX_BUFFER_SIZE) {
		receivedData[bufferIndex] = data;
		bufferIndex++;
	}
}

int main()
{
	
	_delay_ms(1000);
	
	GPIO_init();
	setup_pwm();
	turn_on_off_PWM(ON);
	UART_init(0);
	UART_putc('D');
	_delay_ms(1000);
	turn_on_off_PWM(OFF);
	char enviarmorse[] = "A enviar MORSE\n";
	char buffer_msg[] = "Buffer has smth      \n";
	sei(); // Set interrupts //
	while(1) {
		UART_puts(enviarmorse);
		if (bufferIndex > 0) // Something on the buffer
		{
			UART_puts(buffer_msg);
			turn_on_off_PWM(OFF);
			sendstring = 1;
			cleanstring = true;
			//debug(3);
				
			for (uint8_t ix = 0; ix < bufferIndex; ix++){
				char letter = receivedData[ix];
				switch (letter) {
					case '!':		//envio do codigo MORSE atraves do buzzer
						MORSE = !MORSE;
					break;
					case '-':		//varia entre porta serie ou temperatura
						//INF = !INF;
					break;
					case '&':		//enviar temperatura codigo Morse, ou porta serie
						//MODO = !MODO;
					break;
					case '\r':
						break;		
					default:
						// MORSE(letter)
						convertToMorse((letter));
					break;
				} // End of Switch
			} // End of for loop
			bufferIndex = 0;
			UART_puts((char *)receivedData);
		} // End of if uart buffer is filled

		// Medir temperatura
		// Enviar temperatura por UART
		_delay_ms(1000);
		turn_on_off_PWM(OFF);
	}
	return 0;
}

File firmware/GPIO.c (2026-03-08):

#define F_CPU 8000000UL

#include <avr/io.h>
#include <util/delay.h>
#include <stdbool.h>

#include "GPIO.h"

void GPIO_init(){
	// Set the LED as output
	DDRD |= (1 << LED) | (1 << PD6);
}

void setup_pwm(){
	// Set the pwm pin as output
	DDRB |= (1<<PWM_PIN);
	// Toggle OC1A/OC1B on compare match; Set FAST-PWM Mode
	TCCR1A |= (1 << COM1A0) | (1 << WGM11) | (1 << WGM10);
	TCCR1B |= (1 << WGM13) | (1 << WGM12);
	// Clock Select Bit Description - 64 bit prescaler
	// frequency = 16 000 000 / 64 = 250k
	TCCR1B |= (1 << CS11) | (1 << CS10);
	OCR1A = 100; //(expected 2.5 kHz)
}

void turn_on_off_PWM(bool is_on){
	if(is_on){
		// Code
		TCCR1A |= (1 << COM1A0);
		OCR1A = tone;
		} else {
		// Code
		TCCR1A &= ~(1 << COM1A0);
	}
}


void change_tone(){
	OCR1A = tone;
}

//-----//-----

void debug( unsigned int ciclos){
	
	while (ciclos>0)
	{
		PORTD |= (1 << PORTD7); // LED ON
		_delay_ms(3000);      // Dash duration
		PORTD &= ~(1 << PORTD7); // LED OFF
		_delay_ms(3000);      // Dash duration
		ciclos--;
	}
}

//converter para Morse
void convertToMorse(char character) {
	UART_putc('#');
	UART_puts((char *)"Inside convert morse to convert: ");
	UART_putc(character);
	UART_putc('\n');
	// Convert uppercase letter or number to Morse code
	int index;
	if (character >= 'A' && character <= 'Z') {
		index = character - 'A';
	} else if (character >= 'a' && character <= 'z') {
		index = character - 'a'; // Add the correct offset for lowercase letters
	} else if (character >= '0' && character <= '9') {
		index = character - '0' + 26;
	} else {
		// Character is not a valid uppercase letter or number, ignore or handle accordingly
		return;
	}
	// Loop through each Morse code symbol
	for (int i = 0; morseCode[index][i] != '\0'; i++) {
		// Blink the LED according to the Morse code
		if (morseCode[index][i] == '.') {
			if (MORSE==0){
				
				PORTD &= ~(1 << PORTD6); // LED ON
				}else{
				turn_on_off_PWM(1);
			}
			_delay_ms(200);      // Dot duration
			} else if (morseCode[index][i] == '-') {
			if (MORSE==0){
				PORTD &= ~(1 << PORTD6); // LED ON
				}else{
				turn_on_off_PWM(1);
			}
			_delay_ms(600);      // Dash duration
		}


		PORTD |= (1 << PORTD6); // LED OFF
		turn_on_off_PWM(0);
		_delay_ms(50);       // Inter-symbol gap
	}

	_delay_ms(750); // Inter-character gap
}

const char *morseCode[] = {
	".-",   // A
	"-...", // B
	"-.-.", // C
	"-..",  // D
	".",    // E
	"..-.", // F
	"--.",  // G
	"....", // H
	"..",   // I
	".---", // J
	"-.-",  // K
	".-..", // L
	"--",   // M
	"-.",   // N
	"---",  // O
	".--.", // P
	"--.-", // Q
	".-.",  // R
	"...",  // S
	"-",    // T
	"..-",  // U
	"...-", // V
	".--",  // W
	"-..-", // X
	"-.--", // Y
	"--..", // Z
	"-----", // 0
	".----", // 1
	"..---", // 2
	"...--", // 3
	"....-", // 4
	".....", // 5
	"-....", // 6
	"--...", // 7
	"---..", // 8
	"----."  // 9
};

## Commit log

2026-03-08 Revise README for Temperature to Morse Code Encoder
    Updated project title and provided detailed project overview, hardware design, firmware information, and authors.
2026-03-09 Document hardware design for Morse Code Temperature Encoder
    Added detailed hardware design specifications for the Morse Code Temperature Encoder, including technical specifications, components, and folder contents.
2026-03-09 Enhance README with project documentation overview
    Added detailed project documentation including reports and design analysis for the Morse Code Temperature Encoder project.
2026-03-09 Enhance README with hardware preview section
    Added hardware preview section with PCB layout and model images.
2026-07-15 Acknowledge PCBWay sponsorship in README
    Added a section to acknowledge PCBWay's sponsorship and highlight manufacturing quality.
2026-07-15 Add physical PCB image to README
    Added an image of the physical PCB to the README.
2026-07-15 Update hardware preview table in README
    Added a column for 'Physical Board' in the hardware preview table.
2026-07-15 Update README with Finished Physical Assembly section
    Added a section for Finished Physical Assembly with an image.
2026-07-15 Revise PCBWay sponsorship and quality review details
    Updated the sponsorship section to emphasize quality review and added a personal experience note about working with PCBWay.
